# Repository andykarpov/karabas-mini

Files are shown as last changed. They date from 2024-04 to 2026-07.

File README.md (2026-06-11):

# Karabas-Go Mini

A Spartan-6 based devboard to emulate different retro-computers.



The hardware design and documentation are licensed under [Creative Commons Attribution-NonCommercial-ShareAlike 4.0 International](http://creativecommons.org/licenses/by-nc-sa/4.0/).

FPGA cores, the firmware and other software parts are licensed by their own licenses.

### What's on the board:

- A 25k LE's Spartan-6 FPGA
- RP2040 MCU
- 4x USB Ports
- 2x 2MB 10ns SRAM chips
- 32MB SDRAM chip
- DVI output
- On-board FT812 video processor
- SAM2695 midi synth
- 2x microSD cards
- Tape In/Out interface
- DS3221 RTC
- 1kB EEPROM
- ESP8266 Wi-Fi module
- uBUS expansion connector
- ESP32-S3 as VDAC32 mcu
- CF card

### PCB 

The latest stable PCB revision number is Rev.G.

Warning: RevC,D,F requires a small [HW mod](https://github.com/andykarpov/karabas-mini/blob/master/revF_mod.md)

PCB source project: https://github.com/andykarpov/karabas-mini-pcb

### Pre-production renders:

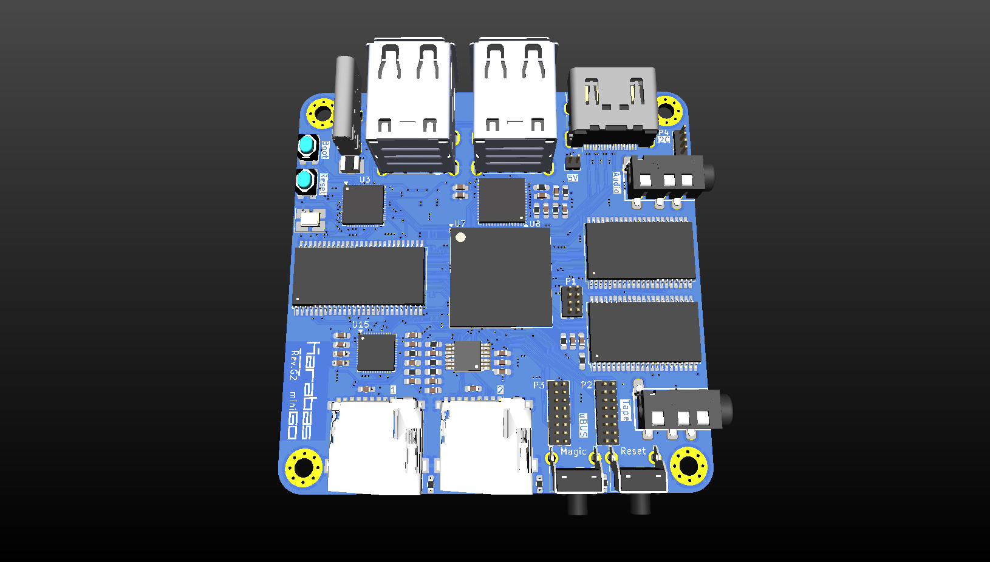
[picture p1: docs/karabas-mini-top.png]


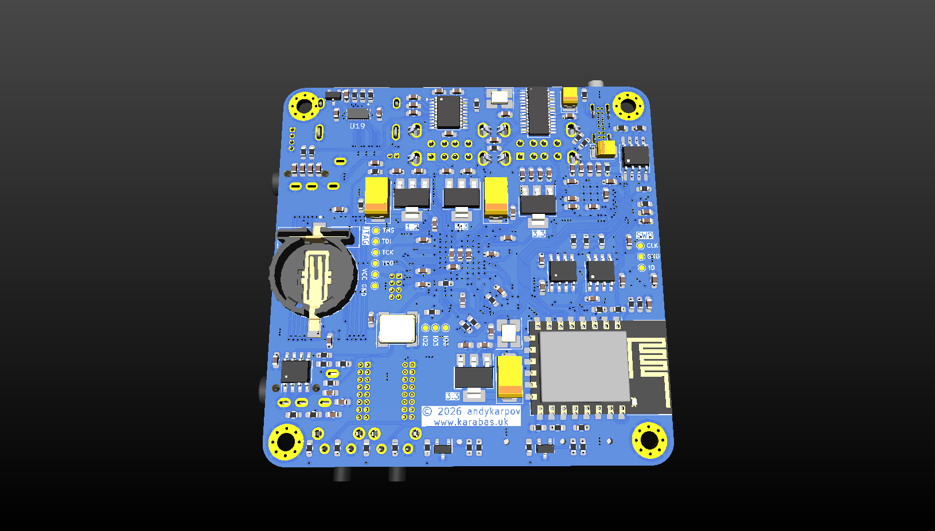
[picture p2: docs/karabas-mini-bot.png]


### Shield with CF card and ESP32-S3 for rev.G (2nd floor)

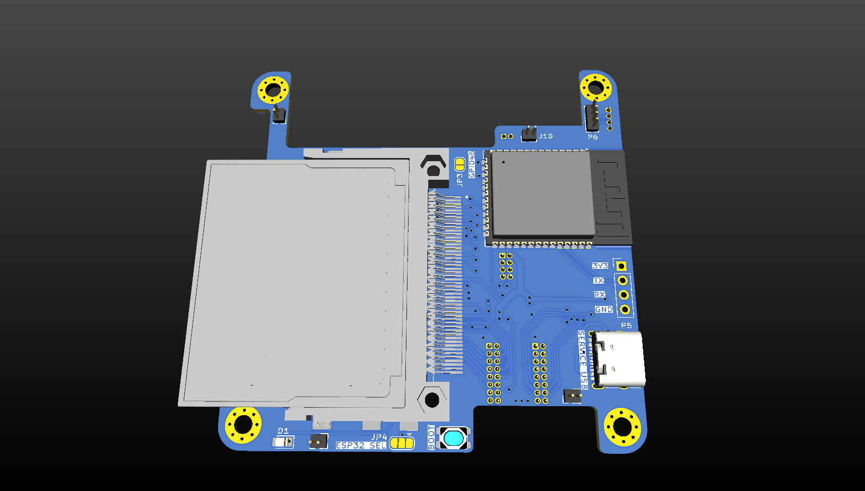
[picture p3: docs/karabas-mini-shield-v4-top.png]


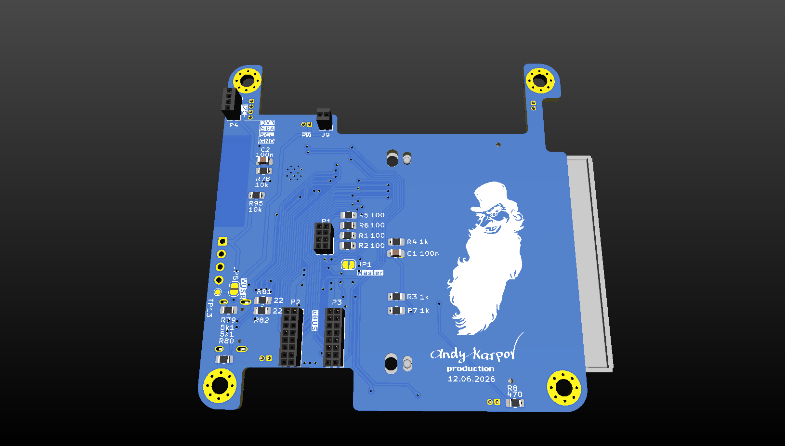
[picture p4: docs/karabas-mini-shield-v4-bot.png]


### Shield for v4 shield with Dot matrix display (3rd floor)

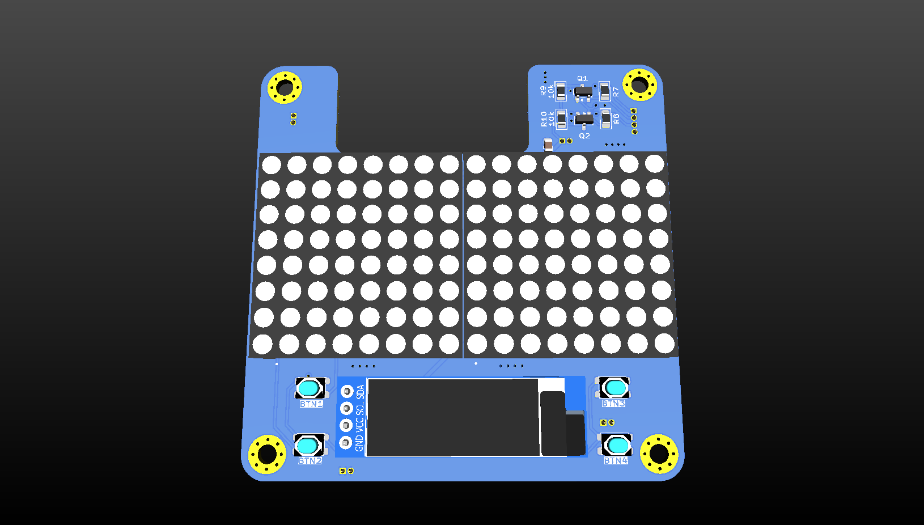
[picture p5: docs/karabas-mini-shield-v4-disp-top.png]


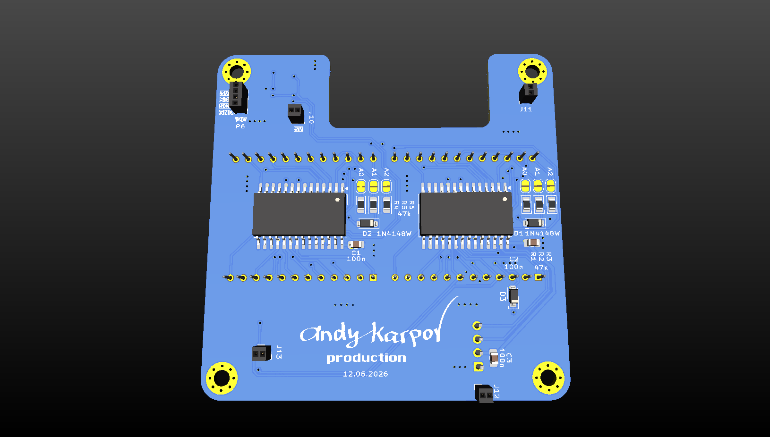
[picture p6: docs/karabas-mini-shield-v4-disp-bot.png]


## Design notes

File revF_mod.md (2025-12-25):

### Required HW mod for all revisions before Rev.G:

The latest cores that uses FT812 chip (boot and tsconf) now requires a generated clock by FPGA instead of 8MHz crystal oscillator.
To perform the mod please do the following:

1. Remove the crystal Y3 (8 MHz)
2. Remove capacitors C40, C41 (18 pF)
3. Find a FPGA net MCU_IO4 and connect it to the Y3 pin 1 by a thin wire





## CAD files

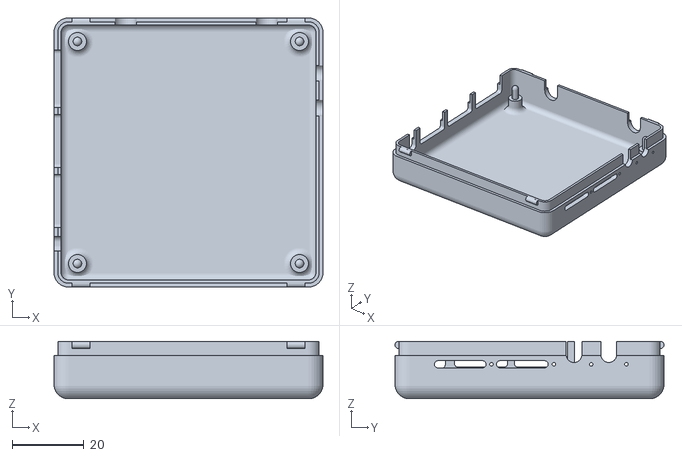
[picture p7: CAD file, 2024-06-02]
case/v2/karabas-mini-case-v2-bottom.stl
75.0 x 75.0 x 16.0

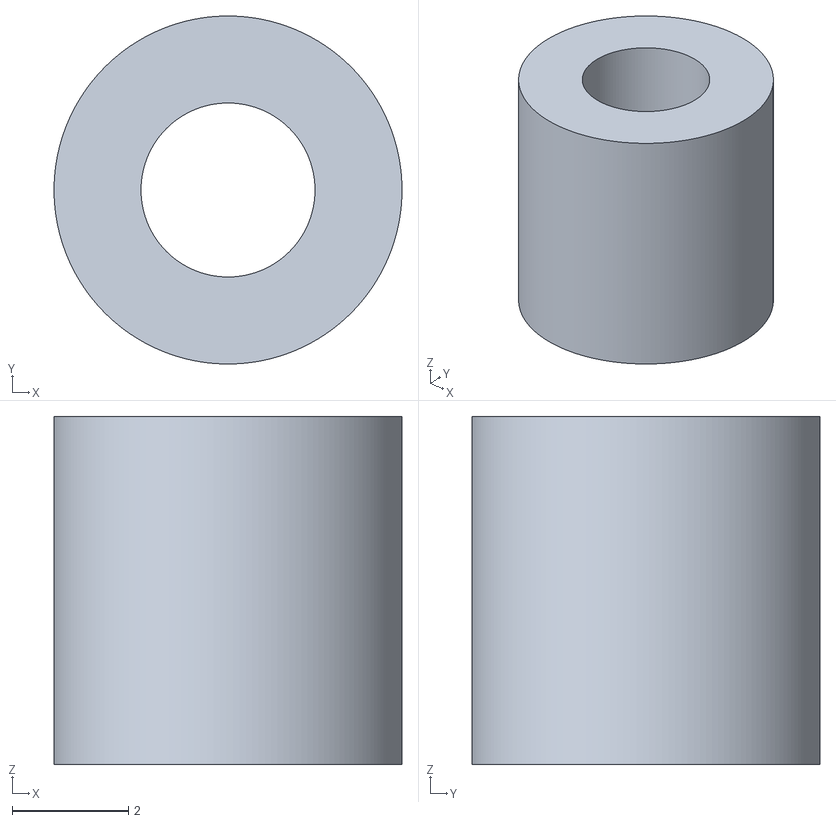
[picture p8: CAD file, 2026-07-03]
case/v2cf/cylinder_6x6x3.stl
6.00 x 6.00 x 6.00

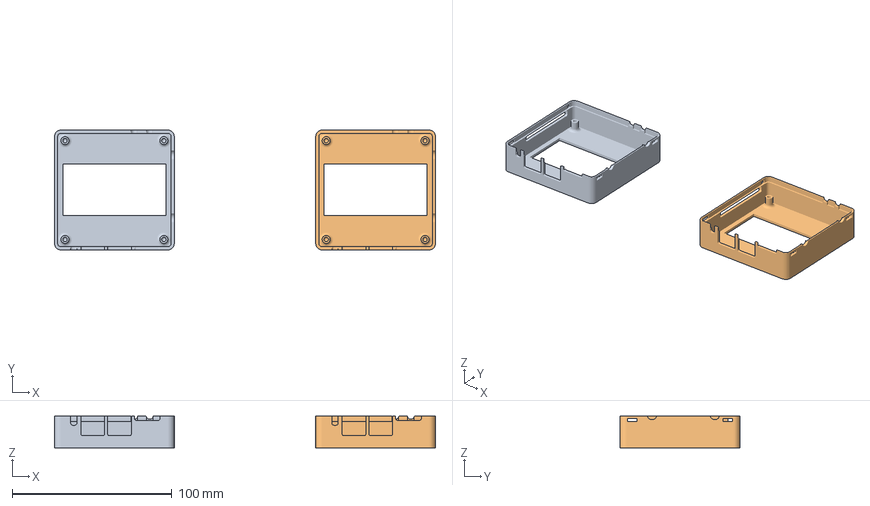
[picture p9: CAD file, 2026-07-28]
case/v4cfdisp/karabas-mini-case-v4cfdisp-top-MMU-LOGO.3mf
238.5 x 75.0 x 20.0 mm

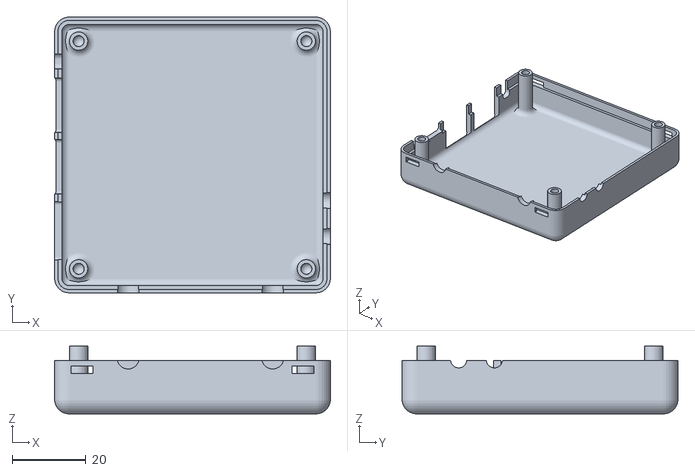
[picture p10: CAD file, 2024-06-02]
case/v2/karabas-mini-case-v2-top.stl
75.0 x 75.0 x 18.4

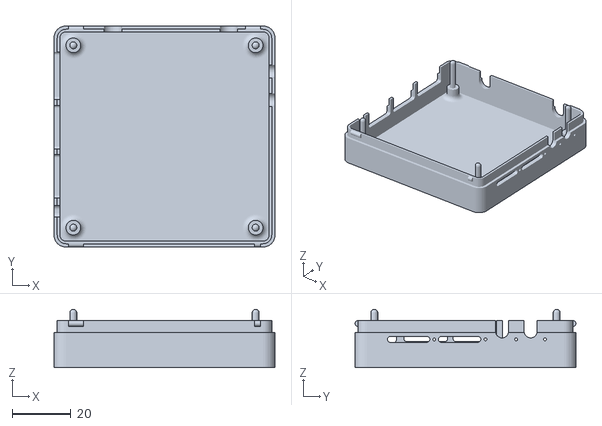
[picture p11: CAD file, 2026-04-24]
case/v2cf/karabas-mini-case-v2cf-bottom.stl
75.0 x 75.0 x 19.8

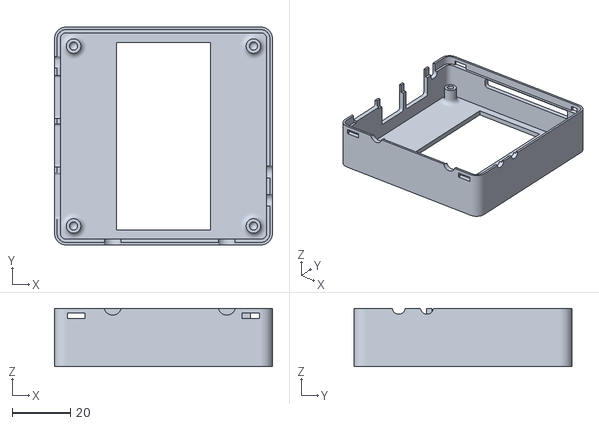
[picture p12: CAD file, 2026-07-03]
case/v4cfdisp/karabas-mini-case-v4cfdisp-top.stl
75.0 x 75.0 x 20.0

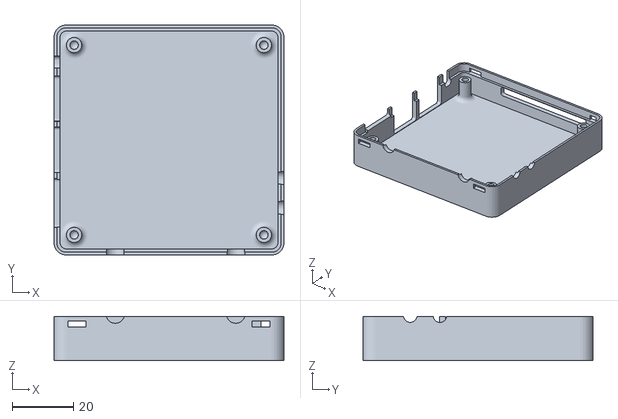
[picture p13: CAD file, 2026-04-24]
case/v2cf/karabas-mini-case-v2cf-top.stl
75.0 x 75.0 x 14.5

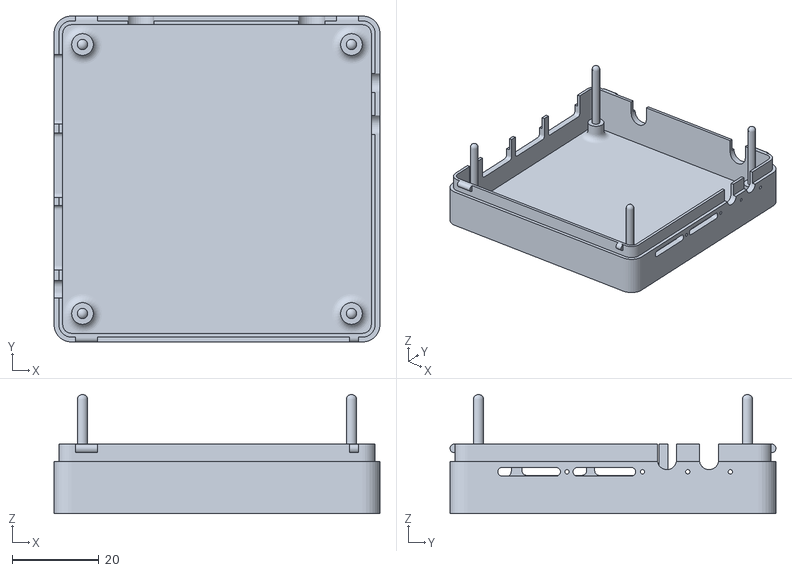
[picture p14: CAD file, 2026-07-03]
case/v4cfdisp/karabas-mini-case-v4cfdisp-bottom.stl
75.0 x 75.0 x 27.4

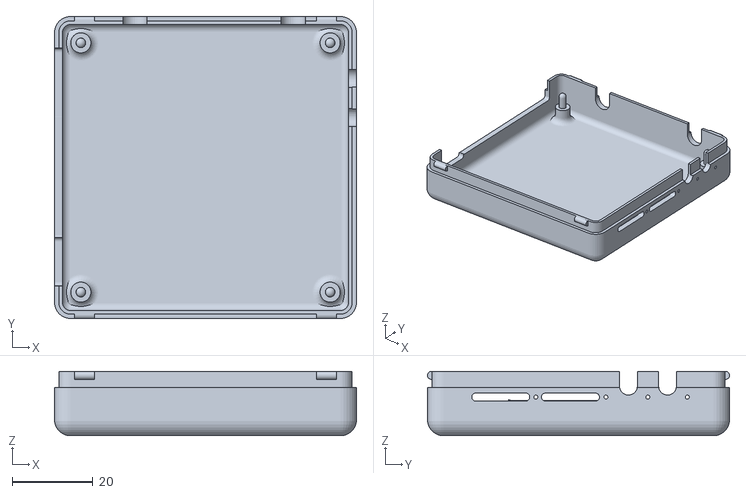
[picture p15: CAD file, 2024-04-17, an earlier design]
case/v1/karabas-mini-case-bottom.stl
75.0 x 75.0 x 16.0

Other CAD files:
case/v1/karabas-mini-case-top.stl

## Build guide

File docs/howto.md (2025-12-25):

# Karabas Go Mini How-to

How to prepare the newly created devboard to run:

1. Prepare an SD card #1 with cores (*.kg2 for rev.C-F3 or *.kg3 for rev.G) and joystick drivers (drivers directory with ini files) in the root of SD card. The SD card should be FAT32 formatted.

2. Upload the RP2040 firmware:

- Press and hold the "RP Boot" button
- Press then release the "RP Reset" button
- Release the "RP Boot" button
- Put the firmware.uf2 (for rev.C - rev.F3) or firmware_g.uf2 renamed to firmware.uf2 (for rev.G) into a mounted drive
- Wait a bit until it reboots
- Done, the boot.kg2 on rev.C-rev.F3 or boot.kg3 on rev.G core should starts
- Please read the manual of each core what to place on SD2 for each of them

3. Upload the ESP32-S3 firmware:

- Close jumper JP11
- Power the main board with USB-C
- Connect a secondary USB-C cable to the upper board
- edit (change the com port address) and run the flash.bat (or flash.sh)
- after successful flashing, remove the JP11 jumper, disconnect both USB-C cables

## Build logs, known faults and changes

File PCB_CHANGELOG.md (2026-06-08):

## Rev.G2

- replaced UDA1334A with PCM5102A
- aligned SDRAM tracks

## Rev.G

- removed crystal from FT812
- removed MCU_IO4 connection from RP2040
- the MCU_IO4 line now repurposed as FT812 8MHz clk generated by FPGA
- disconnected FT_AUDIO, FT_DISPLAY from FPGA
- PWM audio replaced with UDA1334 DAC
- disconnected FT_PD from FPGA, connected to RP2040 as FT_RESET
- disconnected MIDI_CLK from FPGA, replaced with 12 MHz crystal
- disconnected MIDI_RST from FPGA, connected to RP2040
- disconnected ESP_BOOT and ESP_RESET from FPGA
- connected ESP_RESET to RP2040
- connected FT812 GPIO0 and GPIO1 and FT SPI to the uBUS header
- connected free FPGA pins to the uBUS as I2S slave pins
- added optional diode to the HDMI 5V line
- rerouted MCU_SCK, ADC_BCK and FT_CLK to the FPGA globak clock pins

Warning: Due to so many backward incompatible changes in the Rev.G, a dedicated firmware (\_g.uf2) and cores (.kg3) will be released for this revision.
Do not try to install the default firmware and cores (kg2) on this revision!

## Rev.F (F1, F2, F3)

- replaced USB Type-C connector with a flag-style one

## Rev.E

- Skipped

## Rev.D

- Small improvements to the rev.C

## Rev.C

- Initial Revision

## Rev.A, Rev.B

- Unreleased due to broken FPGA pinout

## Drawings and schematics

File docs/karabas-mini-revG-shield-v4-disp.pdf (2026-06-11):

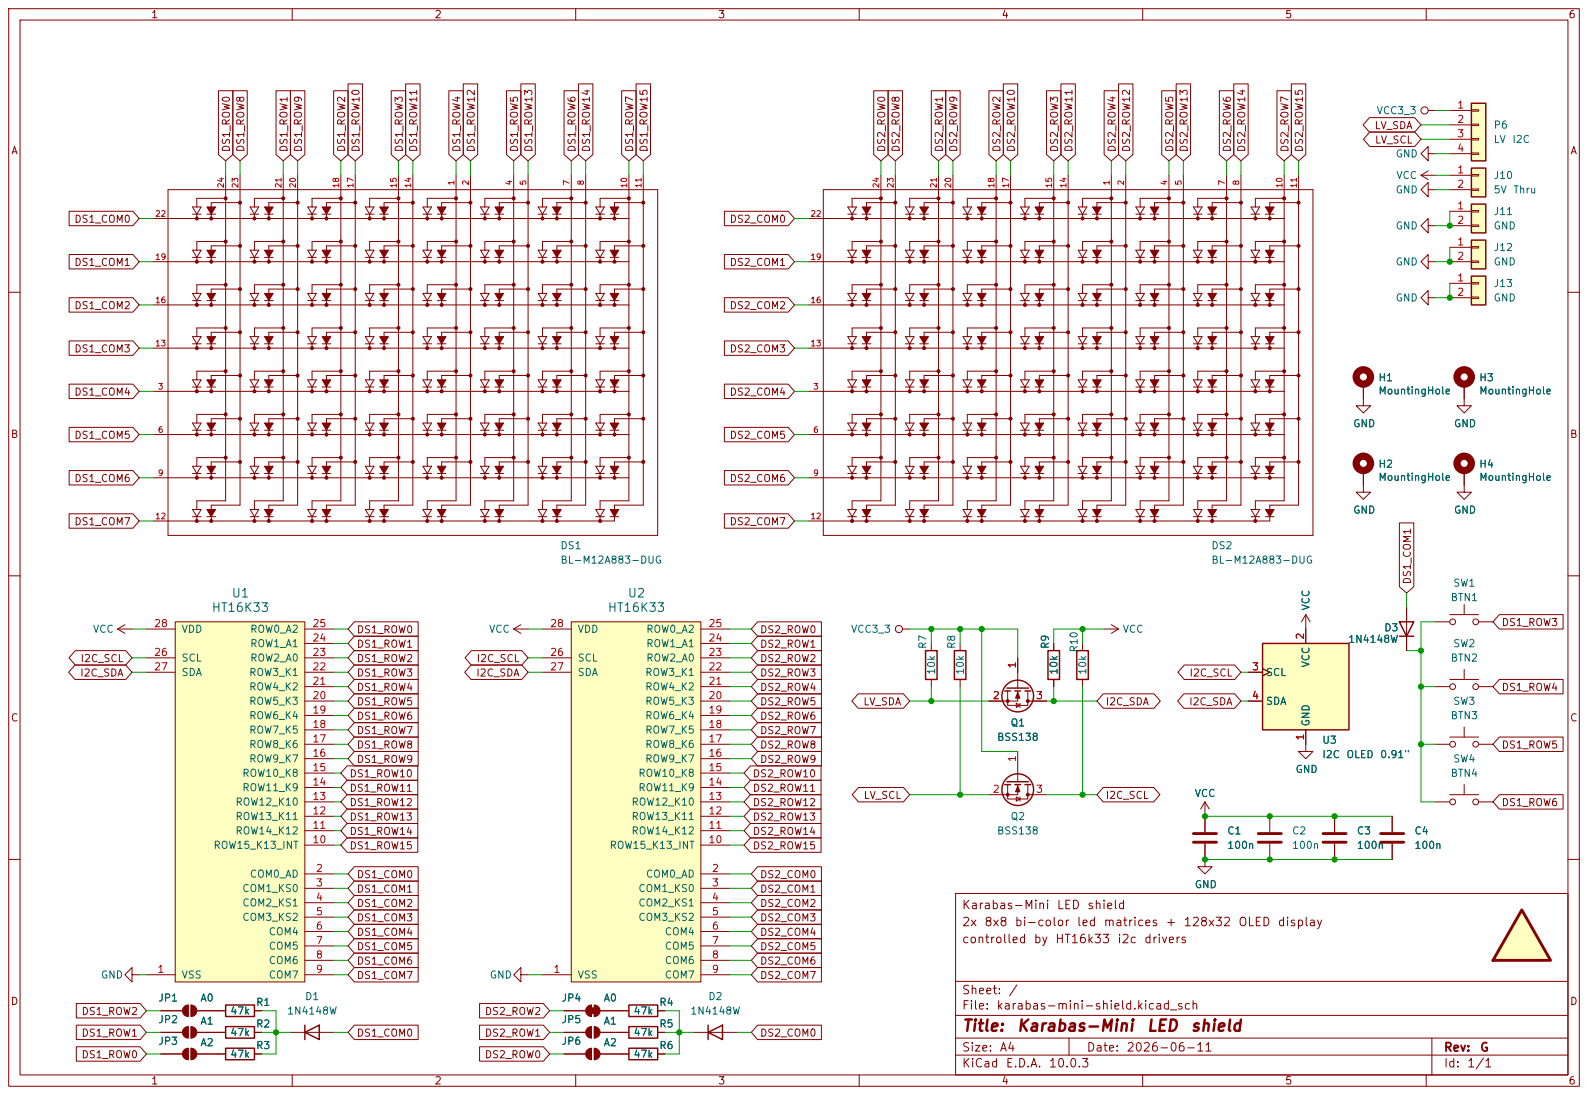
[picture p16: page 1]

Karabas-Mini LED shield
2x 8x8 bi-color led matrices + 128x32 OLED display
controlled by HT16k33 i2c drivers

Sheet: /
File: karabas-mini-shield.kicad_sch
Title: Karabas-Mini LED shield

Size: A4 | Rev: G
KiCad E.D.A. 10.0.3 | Id: 1/1

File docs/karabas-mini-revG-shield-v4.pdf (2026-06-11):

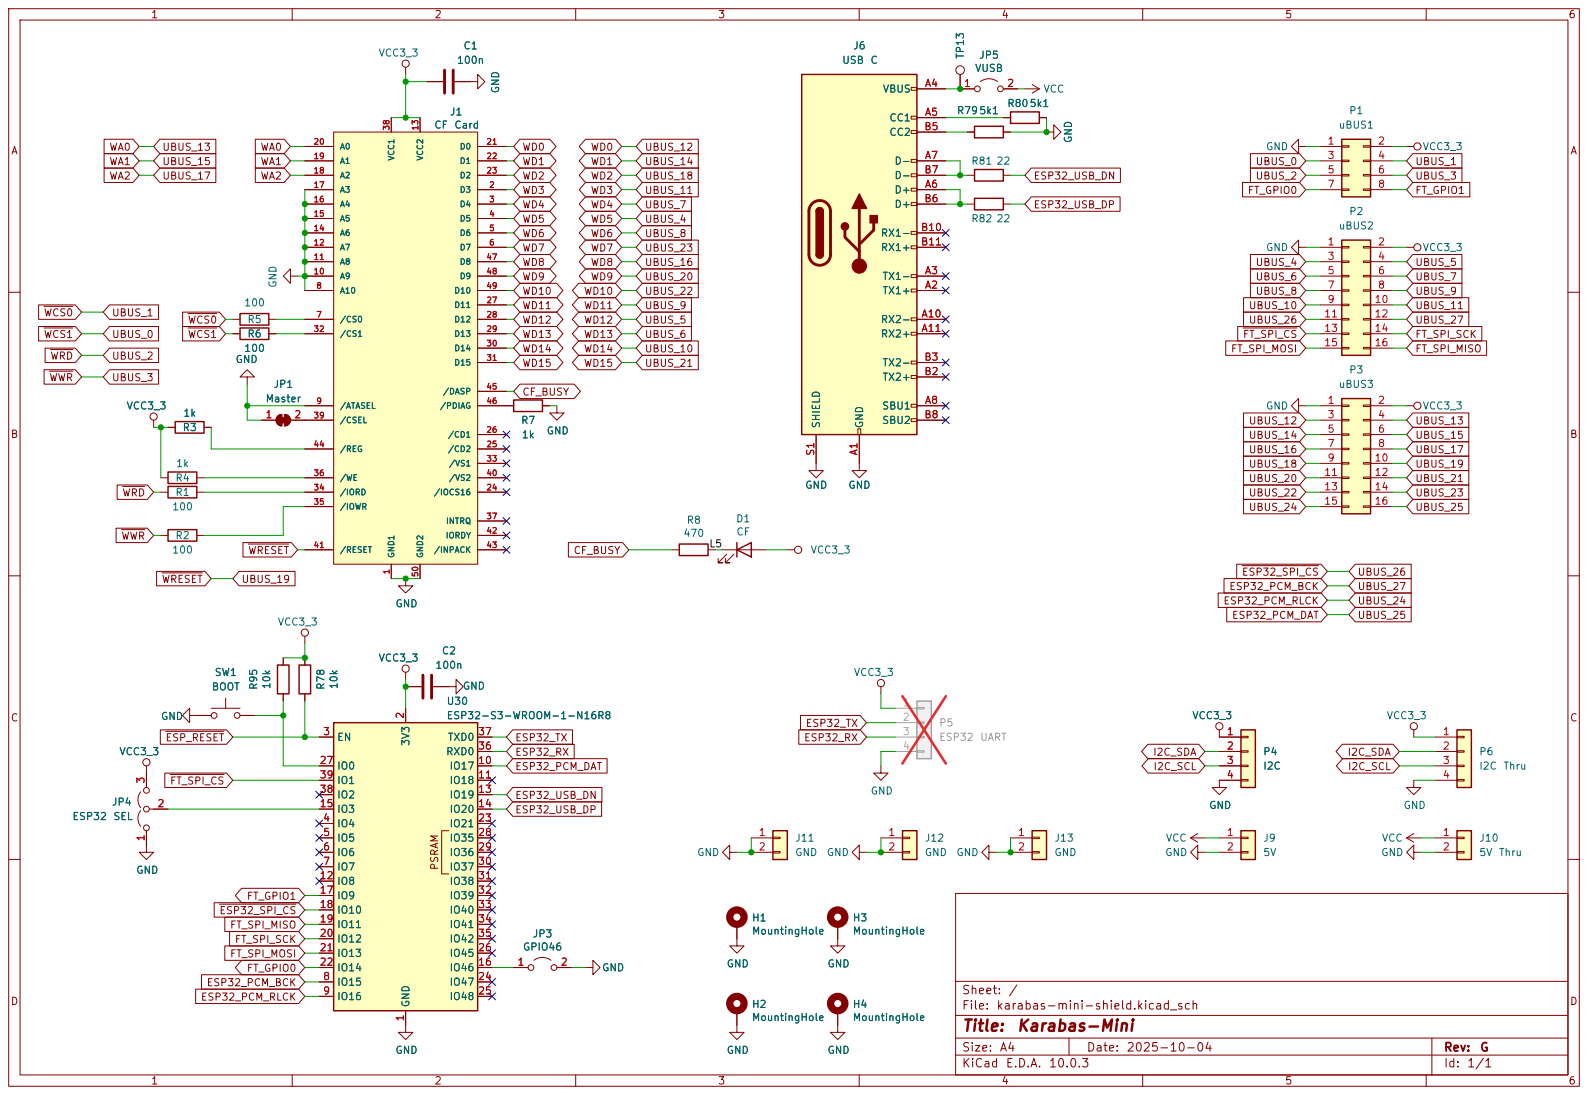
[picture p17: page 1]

Sheet: /
File: karabas-mini-shield.kicad_sch
Title: Karabas-Mini

Size: A4 | Rev: G
KiCad E.D.A. 10.0.3 | Id: 1/1

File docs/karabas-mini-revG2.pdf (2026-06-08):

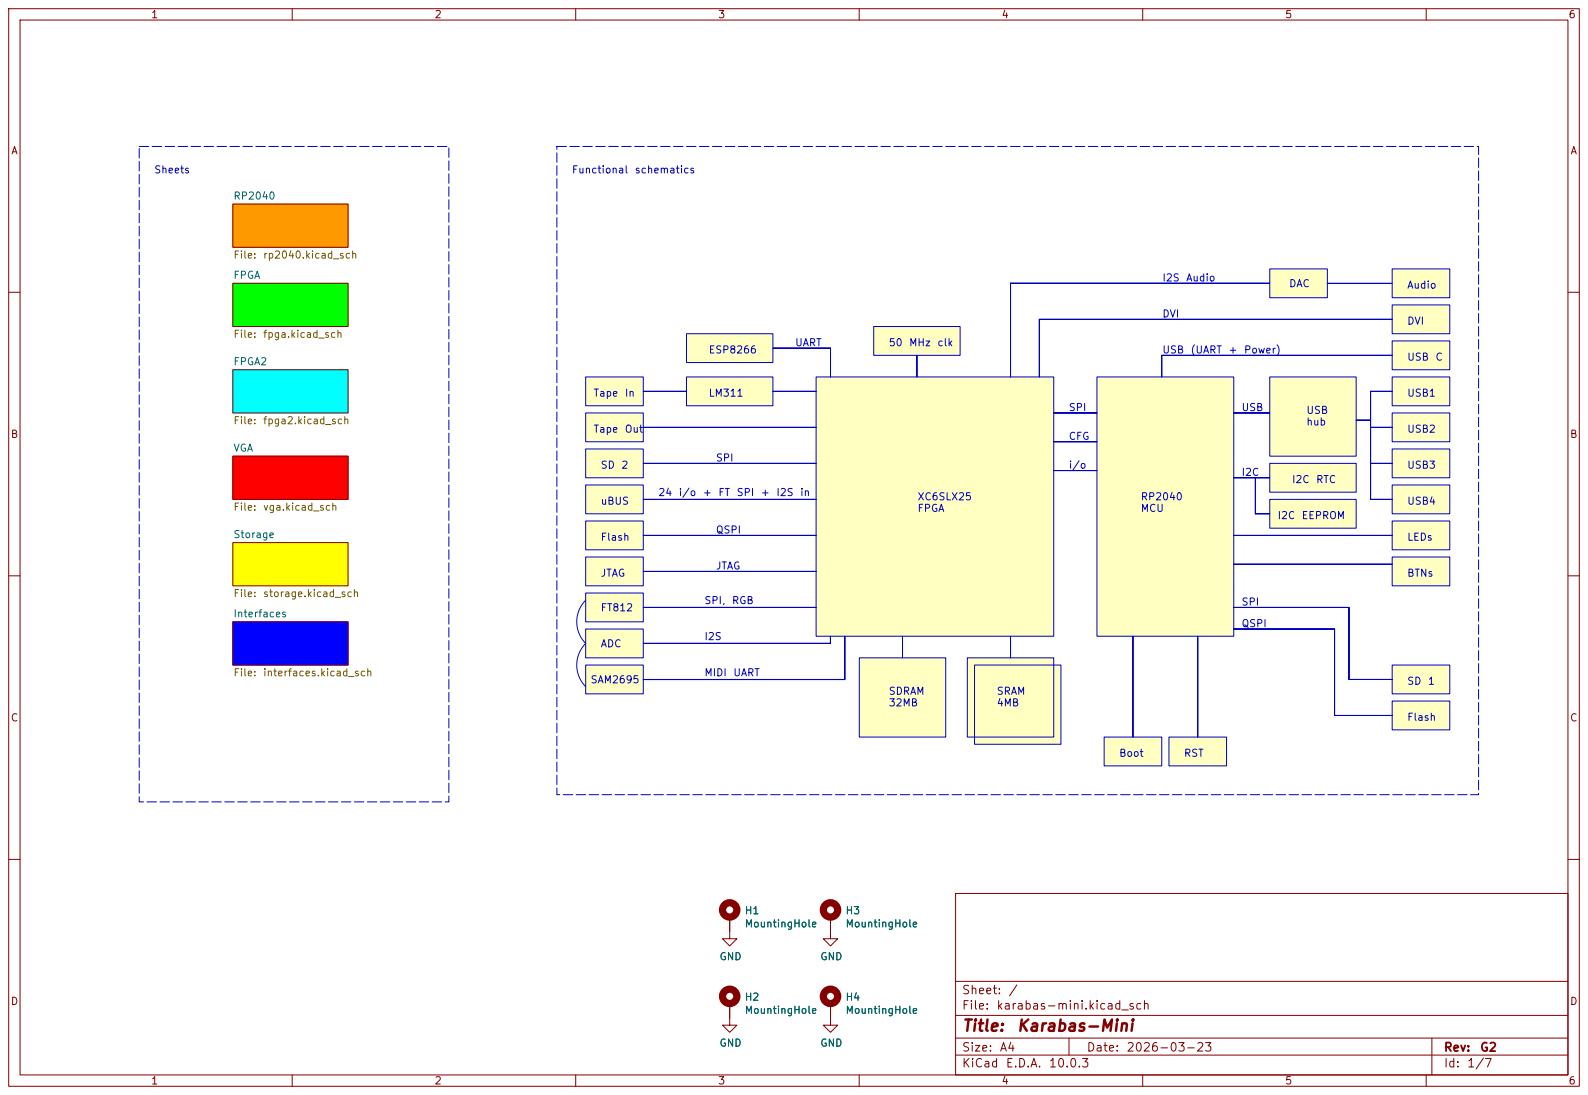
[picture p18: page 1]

Functional schematics 24 i/o + FT SPI + I2S in

Size: A4 | Rev: G2
KiCad E.D.A. 10.0.3 | Id: 1/7

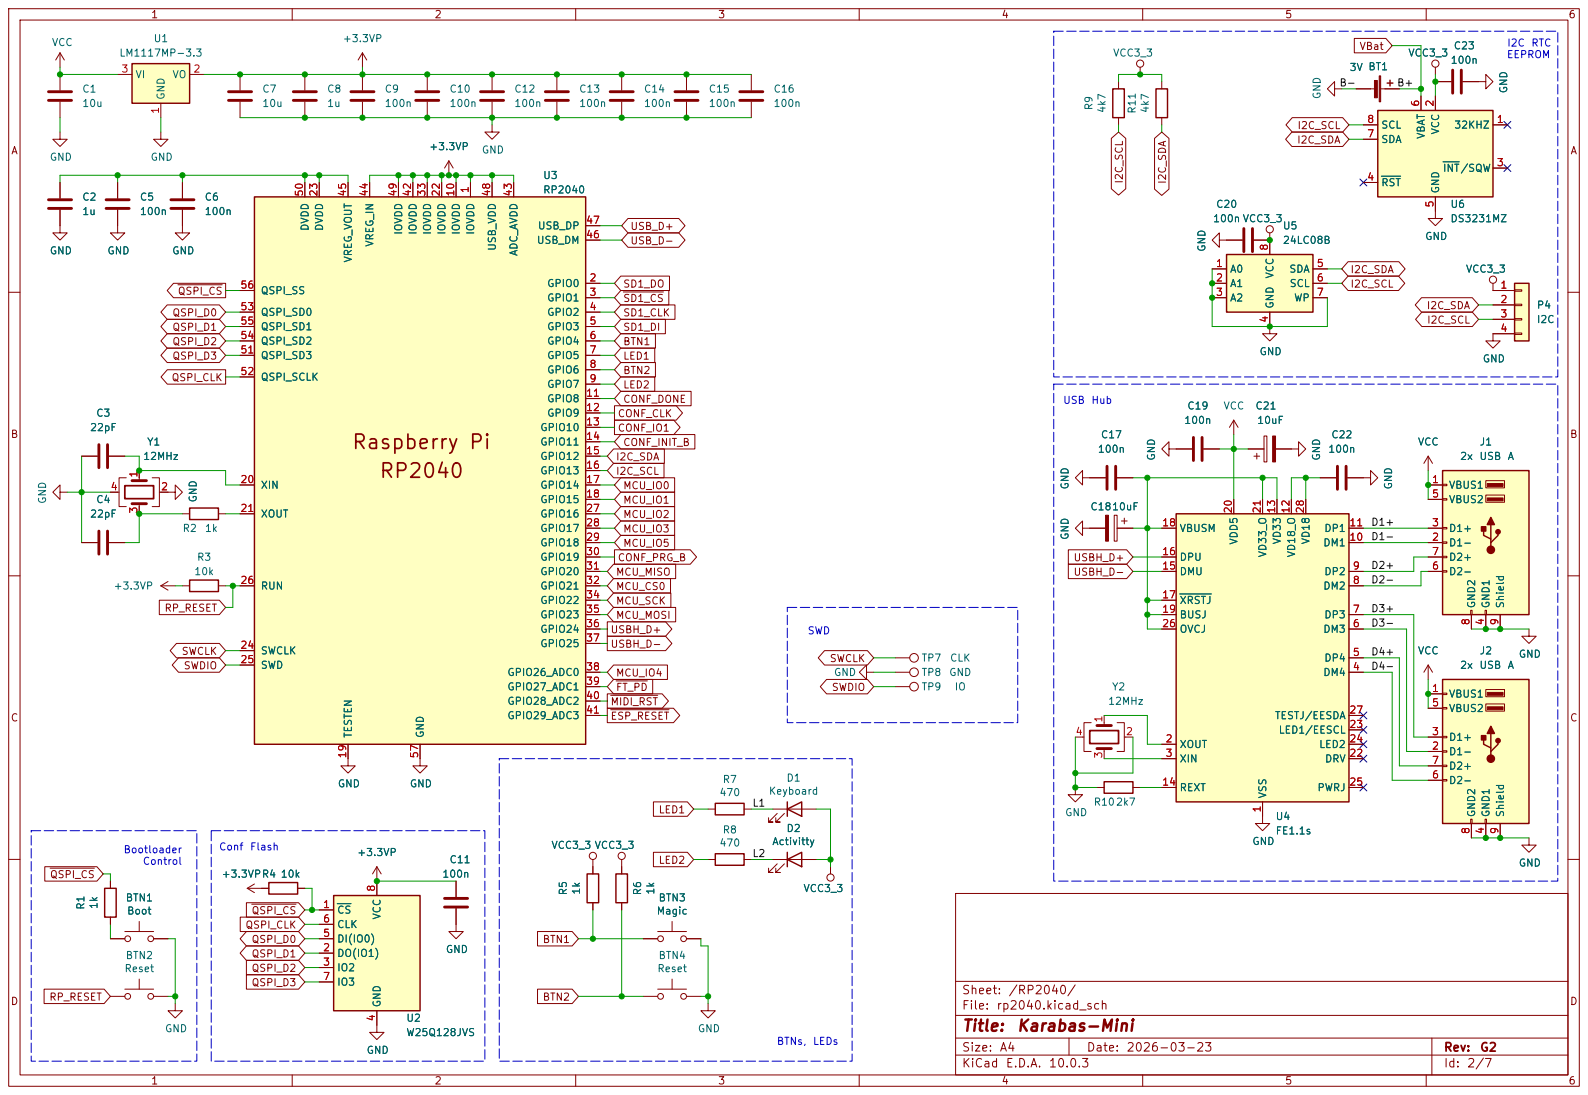
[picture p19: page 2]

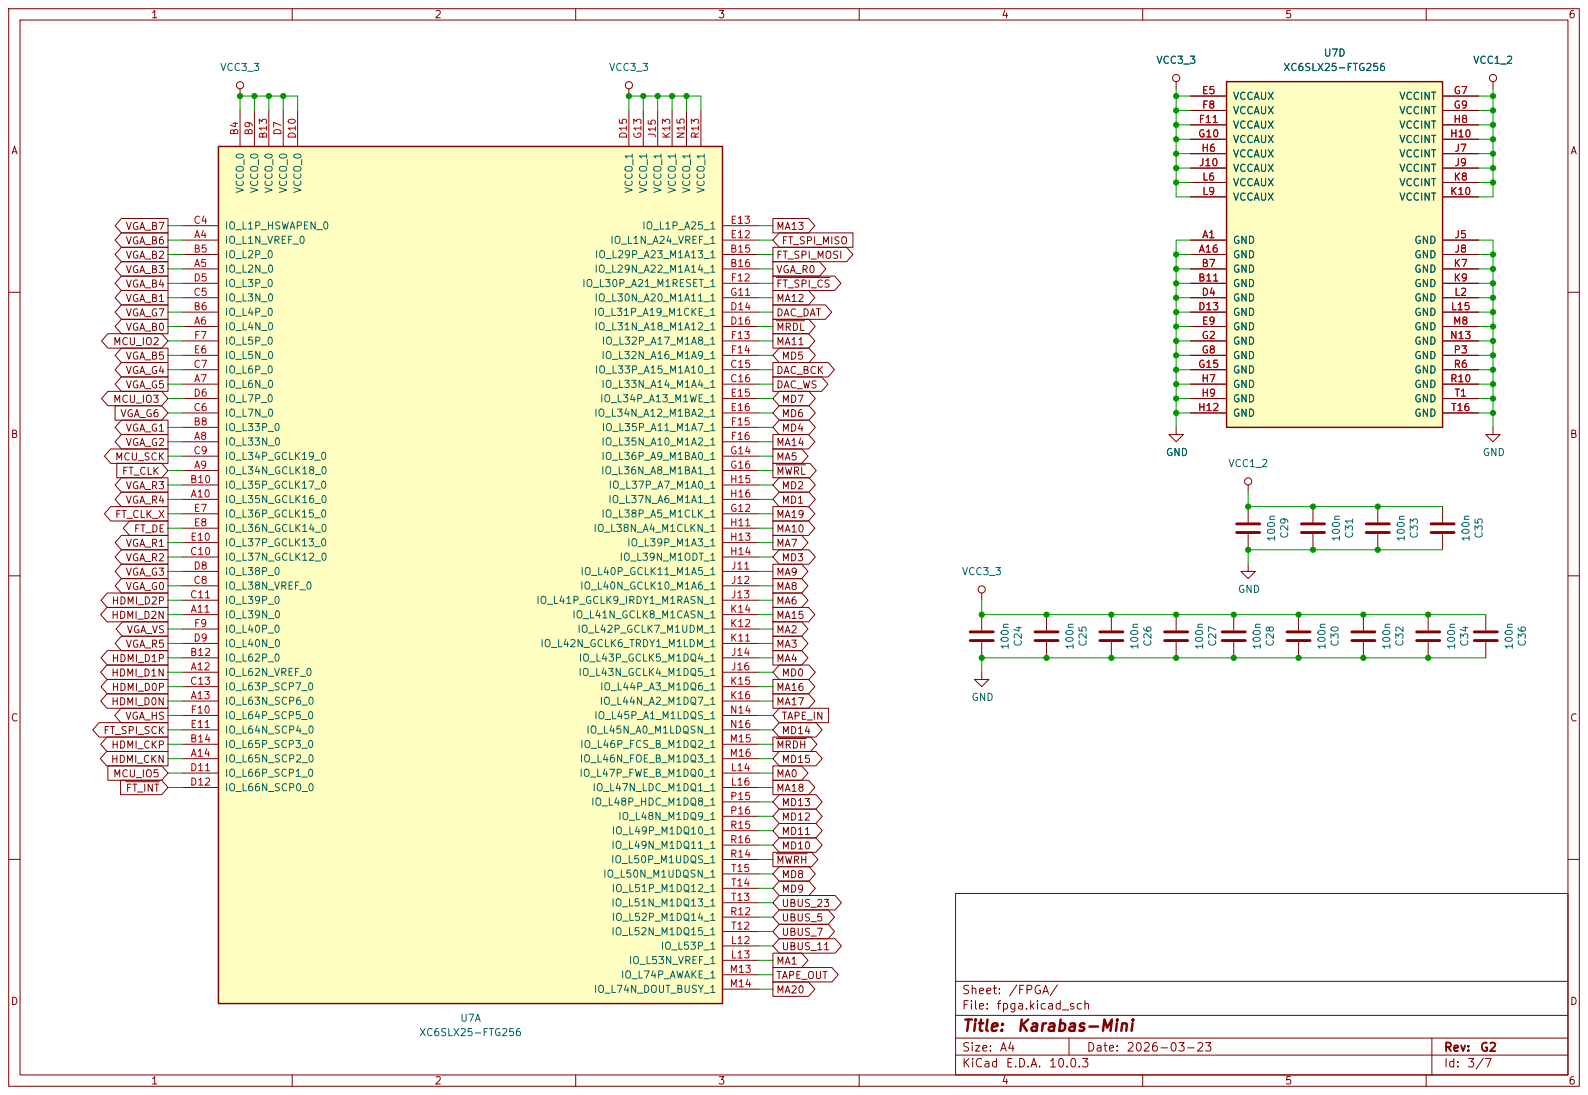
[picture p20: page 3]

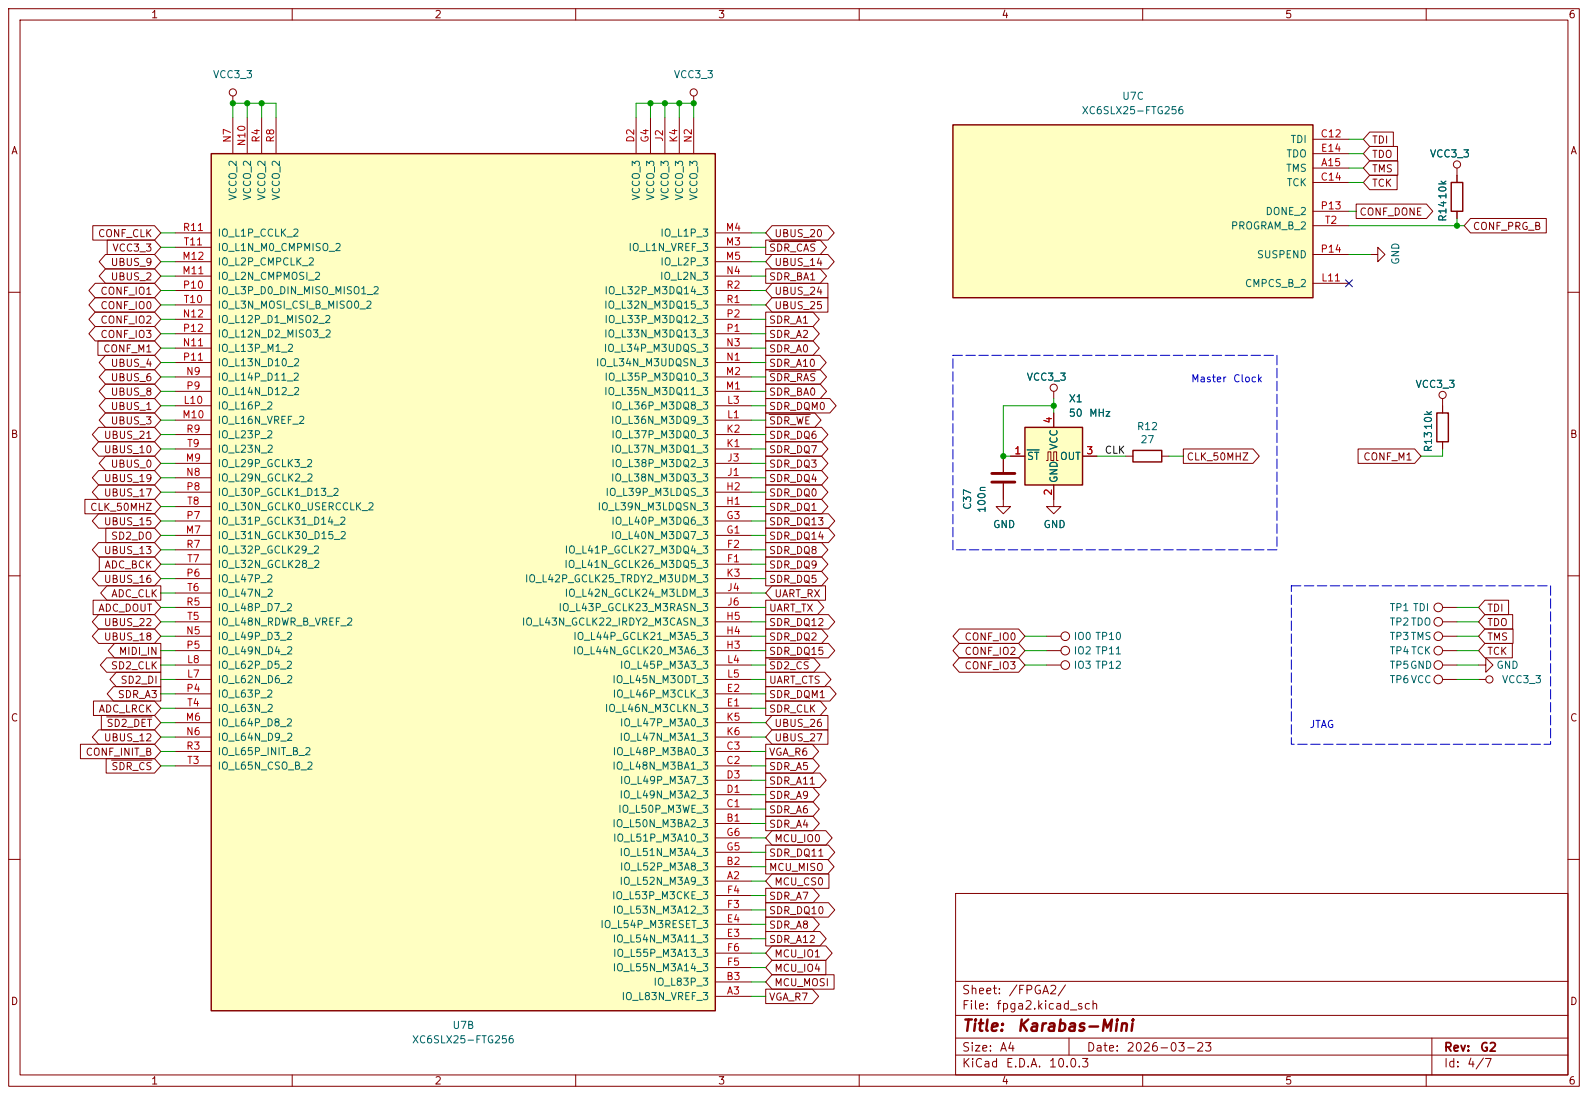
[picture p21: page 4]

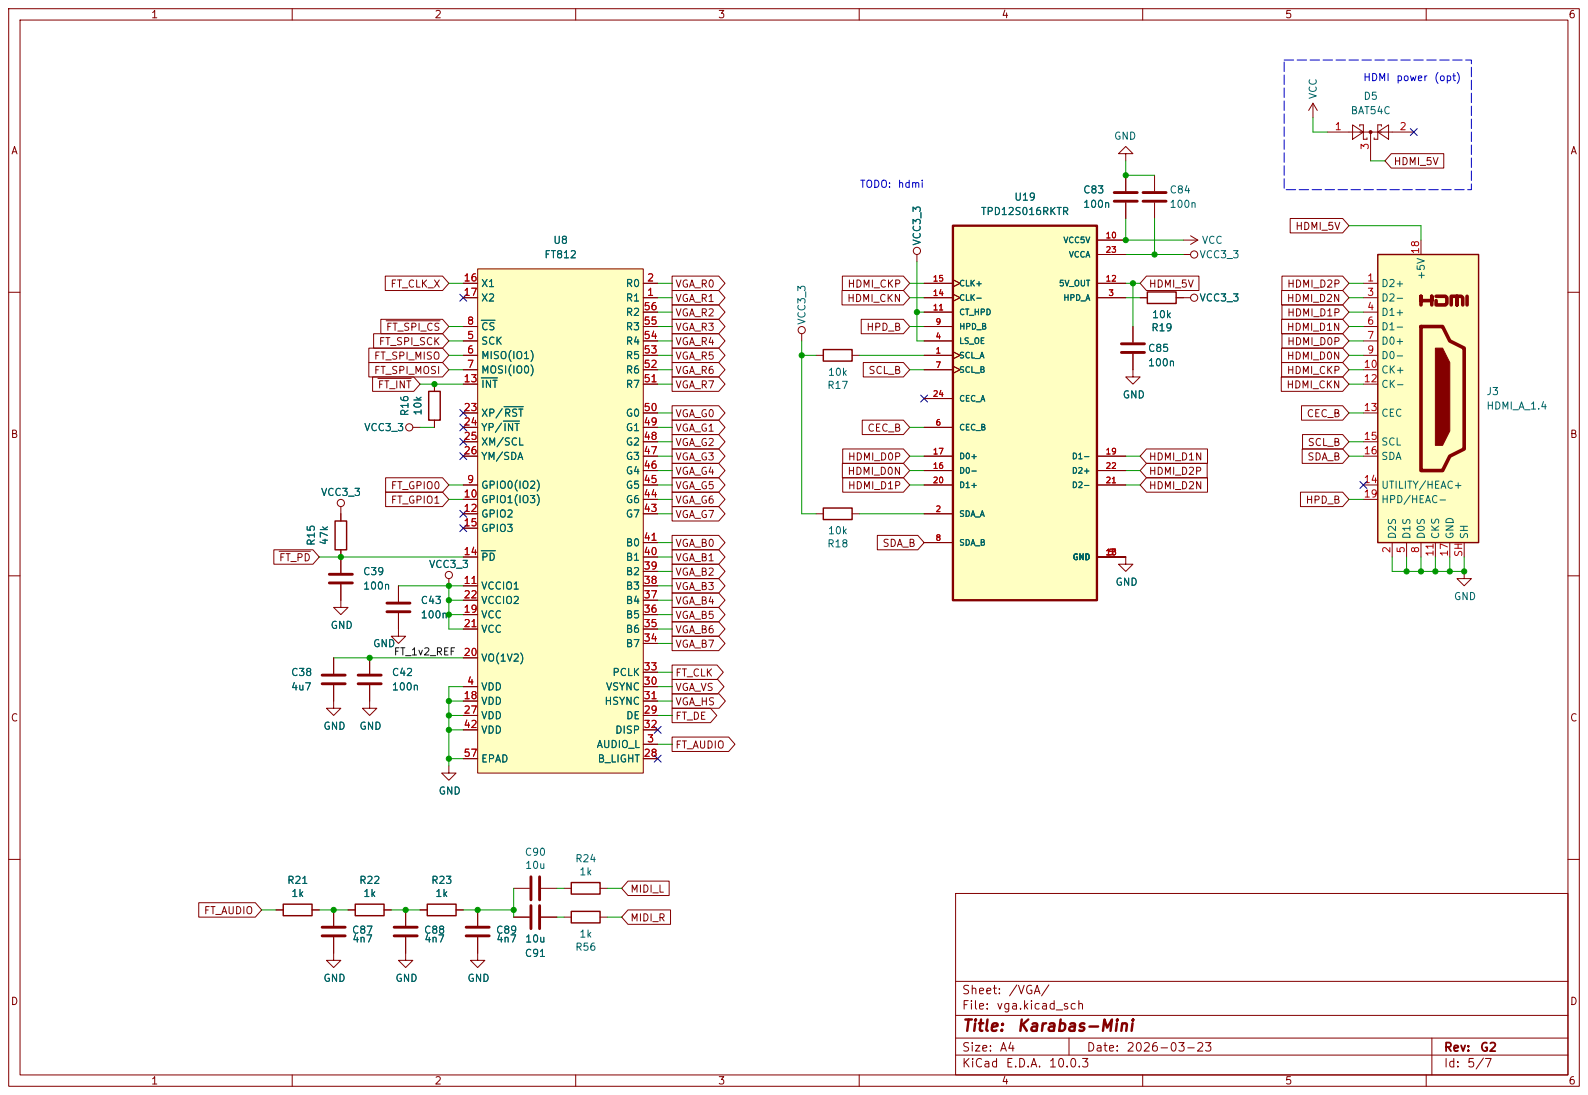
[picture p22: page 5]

XP/RST 23
YP/INT 24
XM/SCL 25
YM/SDA 26
VSYNC 30 HSYNC 31 DISP 32 PCLK 33 B7 34 B6 35 B5 36 B4 37 B3 38 B2 39 B1 40 B0 41

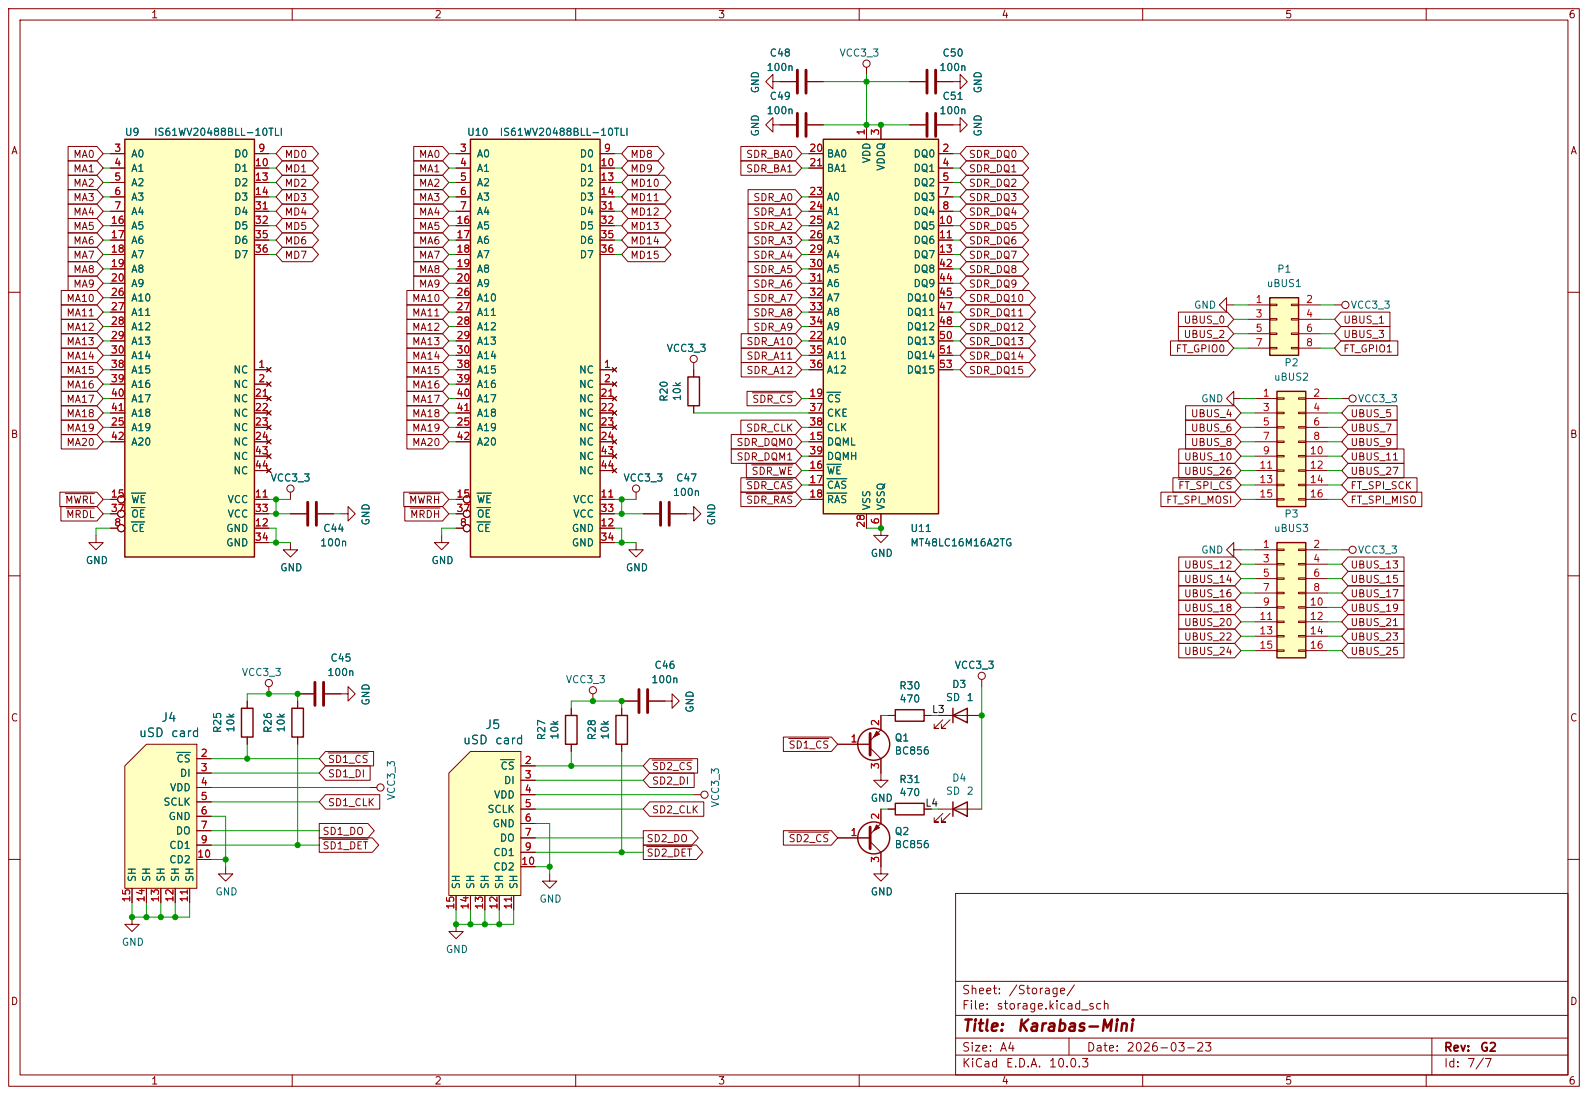
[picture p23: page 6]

6 DQ3 7 DQ4 8 DQ5 10 DQ6 11 DQ7 13 DQML 15 WE 16 CAS 17 RAS 18 CS 19 BA0 20 BA1 21

SCLK 5 GND 6 DO 7 CD1 9 CD2 10 SH 11 SH 12 SH 13 SH 14 SH 15

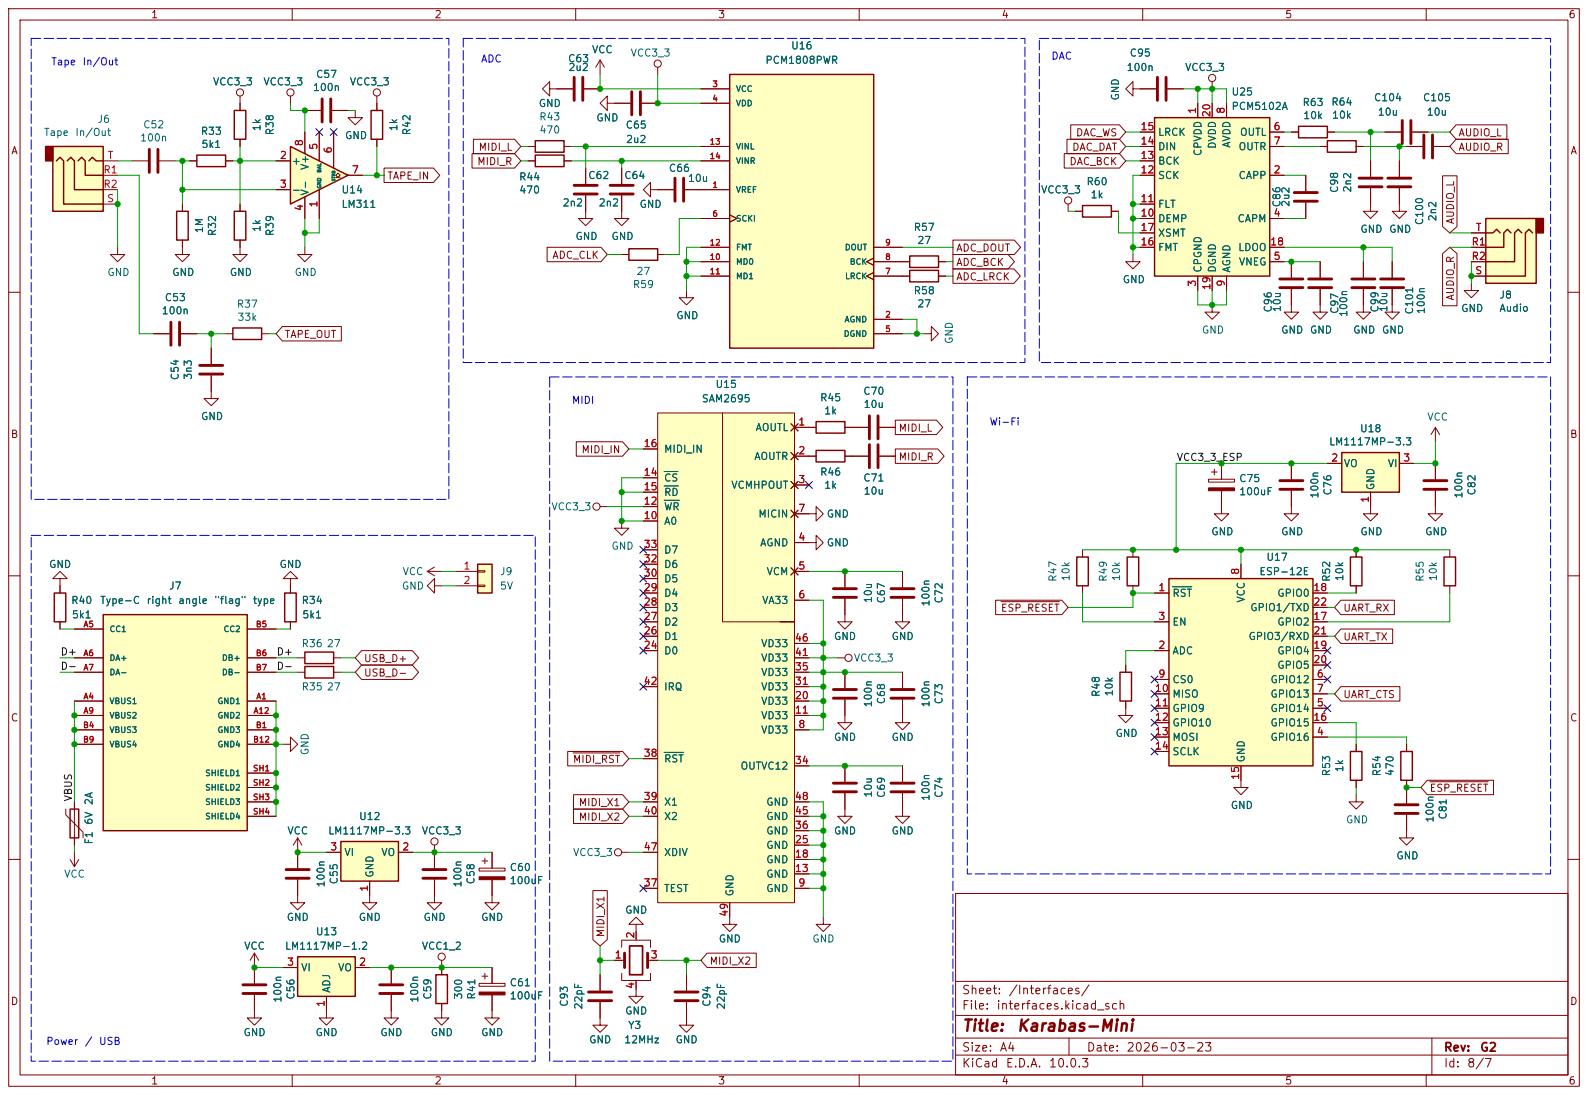
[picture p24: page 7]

10u C98 2n2 GND
SCK 12 BCK 13 DIN 14 LRCK 15

Type-C right angle "flag" type 100n C56 R35 27 R34
Type-C right angle "flag" type

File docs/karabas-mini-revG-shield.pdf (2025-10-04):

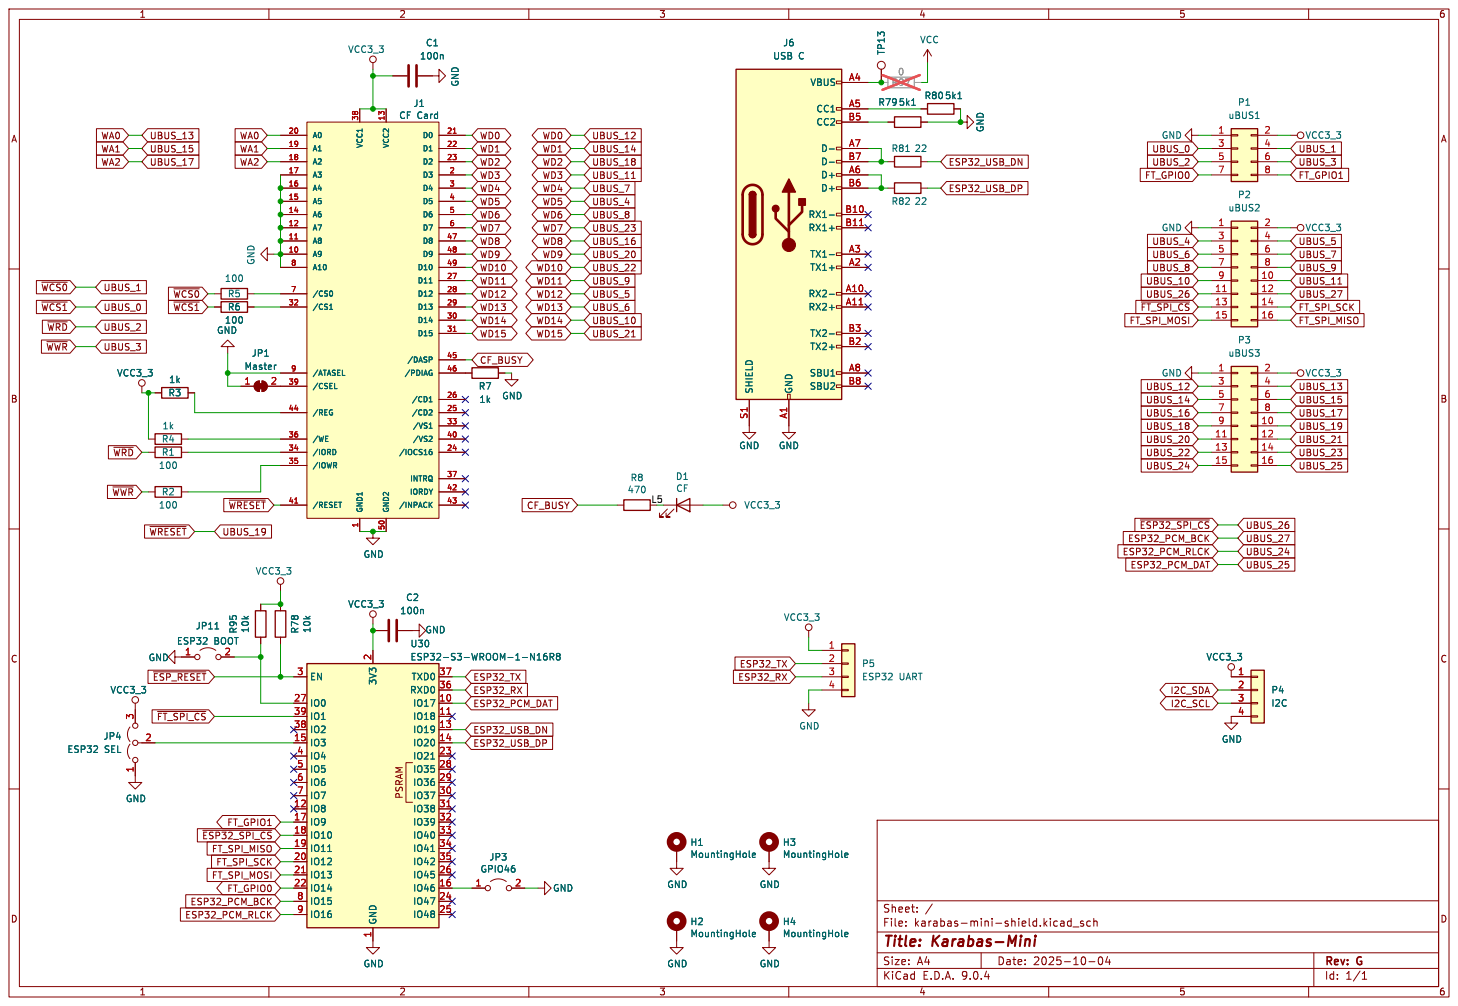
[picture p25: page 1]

Id: 1/1 Title: Karabas-Mini File: karabas-mini-shield.kicad_sch Sheet: / GND

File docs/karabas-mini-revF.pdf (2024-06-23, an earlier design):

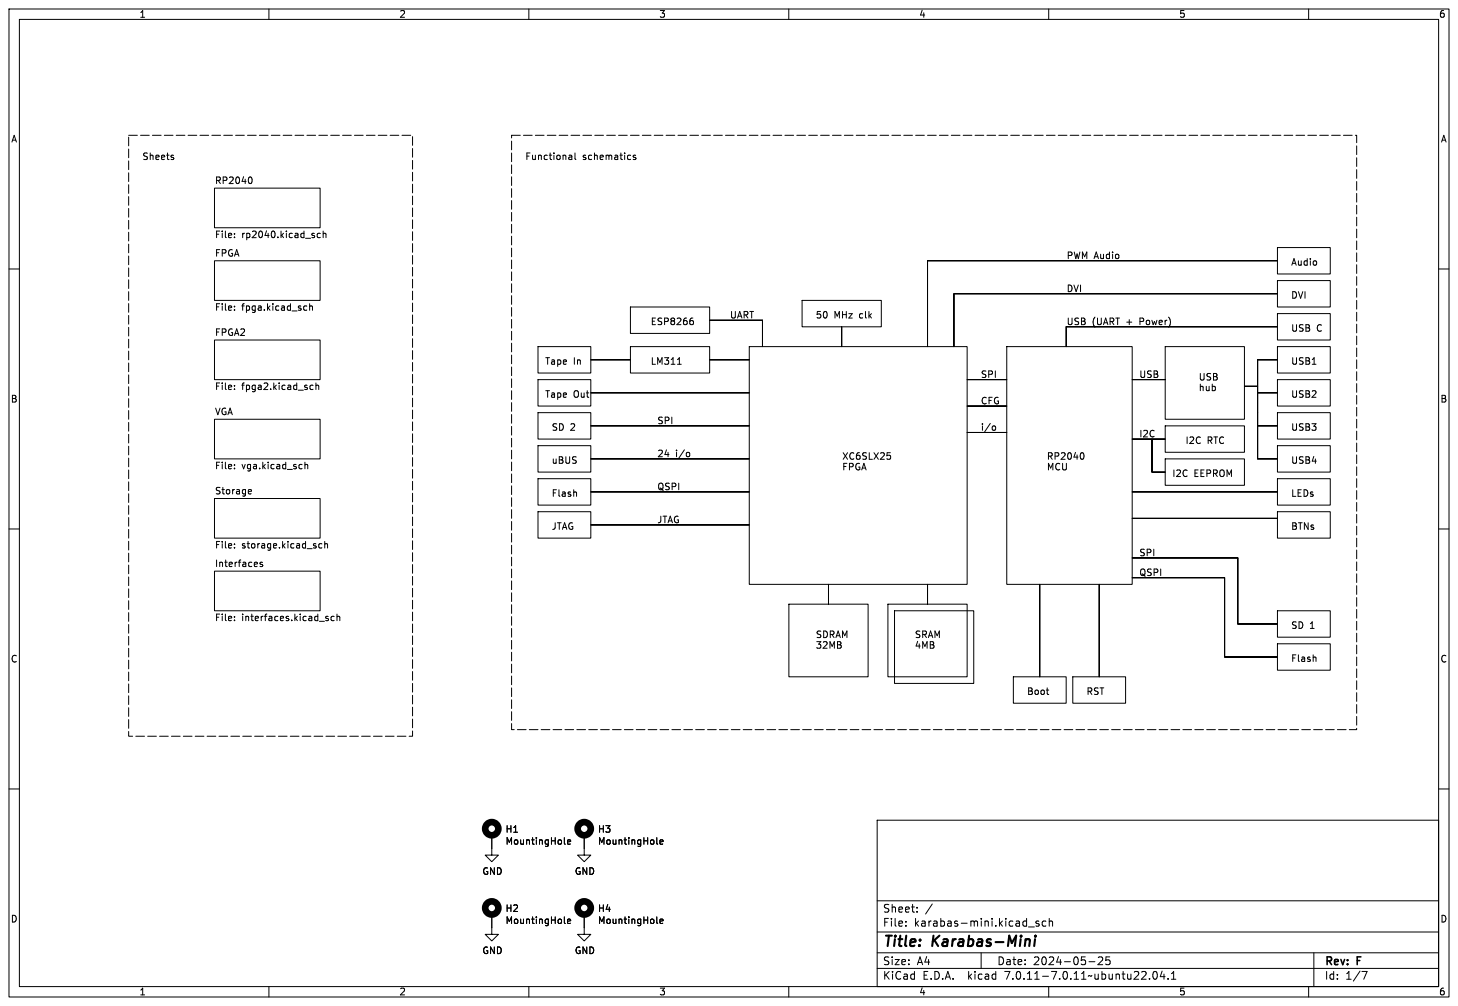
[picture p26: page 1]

File: fpga.kicad_sch RP2040 File: rp2040.kicad_sch VGA
Interfaces File: interfaces.kicad_sch FPGA

Id: 1/7 Title: Karabas-Mini File: karabas-mini.kicad_sch Sheet: /

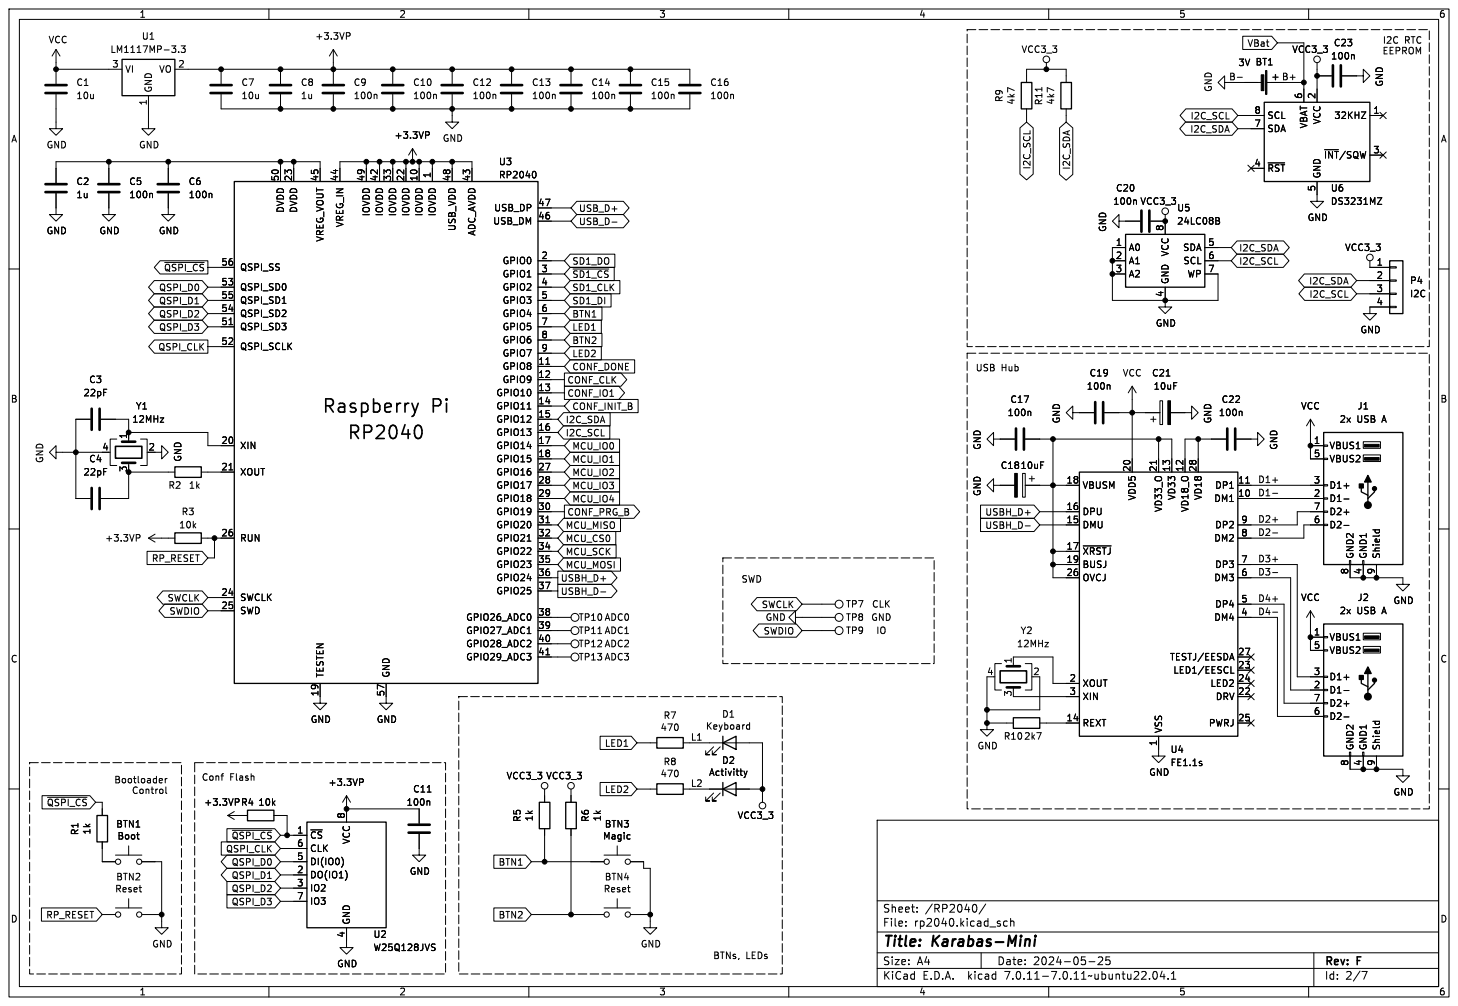
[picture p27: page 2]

6 SDA 7 SCL 8 U6 DS3231MZ GND R9 4k7 VCC3_3 GND GND R11 4k7 VCC C21

6 SDA 7 SCL 8 GND GND

1 IOVDD 10 GPIO8 11 GPIO9 12 GPIO10 13 GPIO11 14 GPIO12 15 GPIO13 16 GPIO14 17 GPIO15 18 TESTEN 19 GPIO0 2 XIN 20 XOUT 21 IOVDD 22 DVDD 23 SWCLK 24 SWD 25 RUN 26 GPIO16 27 GPIO17 28 GPIO18 29 GPIO1 3 GPIO19 30 GPIO20 31 GPIO21 32 IOVDD 33 GPIO22 34 GPIO23 35 GPIO24 36 GPIO25 37 GPIO26_ADC0 38 GPIO27_ADC1 39 GPIO2 4 GPIO28_ADC2 40 GPIO29_ADC3 41 IOVDD 42 ADC_AVDD 43 VREG_IN 44 VREG_VOUT 45 USB_DM 46 USB_DP 47 USB_VDD 48 IOVDD 49 GPIO3 5 DVDD 50 QSPI_SD3 51 QSPI_SCLK 52 QSPI_SD0 53 QSPI_SD2 54 QSPI_SD1 55 QSPI_SS 56 GND 57 GPIO4 6 GPIO5 7 GPIO6 8 GPIO7 9 U3 RP2040 TP11 ADC1 C2

1 IOVDD 10 GPIO8 11 GPIO9 12 GPIO10 13 GPIO11 14 GPIO12 15 GPIO13 16 GPIO14 17 GPIO15 18 TESTEN 19 GPIO0 2 XIN 20 XOUT 21 IOVDD 22 DVDD 23 SWCLK 24 SWD 25 RUN 26 GPIO16 27 GPIO17 28 GPIO18 29 GPIO1 3 GPIO19 30 GPIO20 31 GPIO21 32 IOVDD 33 GPIO22 34 GPIO23 35 GPIO24 36 GPIO25 37 GPIO26_ADC0 38 GPIO27_ADC1 39 GPIO2 4 GPIO28_ADC2 40 GPIO29_ADC3 41 IOVDD 42 ADC_AVDD 43 VREG_IN 44 VREG_VOUT 45 USB_DM 46 USB_DP 47 USB_VDD 48 IOVDD 49 GPIO3 5 DVDD 50 QSPI_SD3 51 QSPI_SCLK 52 QSPI_SD0 53 QSPI_SD2 54 QSPI_SD1 55 QSPI_SS 56 GND 57 GPIO4 6 GPIO5 7 GPIO6 8 GPIO7 9 Y1
TP10 ADC0 C5

4 SDA 5 SCL 6 WP 7 VCC

1 DM1 10 DP1 11 VD18_O 12 VD33 13 REXT 14 DMU 15 DPU 16 ~{XRSTJ} 17 VBUSM 18 BUSJ 19 XOUT 2 VDD5 20 VD33_O 21 DRV 22

Id: 2/7 Title: Karabas-Mini File: rp2040.kicad_sch Sheet: /RP2040/



Id: 4/7 Title: Karabas-Mini File: fpga2.kicad_sch Sheet: /FPGA2/


Id: 5/7 Title: Karabas-Mini File: vga.kicad_sch Sheet: /VGA/ C87


1 DQ5 10 DQ6 11 DQ7 13 DQML 15 ~{WE} 16 ~{CAS} 17 ~{RAS} 18 ~{CS} 19 DQ0 2 BA0 20 BA1 21 A10 22 A0 23 A1 24 A2 25 A3 26 VSS 28 A4 29 VDDQ

3 A5 30 A6 31 A7 32 A8 33 A9 34 A11 35 A12 36 CKE 37 CLK 38 DQMH 39 DQ1 4 DQ8 42 DQ9 44 DQ10 45 DQ11 47 DQ12 48 DQ2 5 DQ13 50 DQ14 51 DQ15 53 VSSQ

uBUS3 CD2 10 SH 11 SH 12 SH 13 SH 14 SH 15

~{CS}2 DI 3 VDD 4 SCLK 5 GND 6 DO 7 CD1 9 J4

~{CS}2 DI 3 VDD 4 SCLK 5 GND 6 DO 7 CD1 9 J5


1 VO 2 VI 3 GND GND GND GND R53 1k C75

8 CS0 9 U17 ESP-12E GND C81 100n R54 470 GND GND

1 VO 2 VI 3 VCC GND C59 100n GND

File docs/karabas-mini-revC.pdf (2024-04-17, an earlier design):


File: fpga.kicad_sch RP2040 File: rp2040.kicad_sch VGA
Interfaces File: interfaces.kicad_sch FPGA

Id: 1/7 Title: Karabas-Mini File: karabas-mini.kicad_sch Sheet: /


6 SDA 7 SCL 8 U6 DS3231MZ GND GND GND GND

6 SDA 7 SCL 8 GND GND

1 IOVDD 10 GPIO8 11 GPIO9 12 GPIO10 13 GPIO11 14 GPIO12 15 GPIO13 16 GPIO14 17 GPIO15 18 TESTEN 19 GPIO0 2 XIN 20 XOUT 21 IOVDD 22 DVDD 23 SWCLK 24 SWD 25 RUN 26 GPIO16 27 GPIO17 28 GPIO18 29 GPIO1 3 GPIO19 30 GPIO20 31 GPIO21 32 IOVDD 33 GPIO22 34 GPIO23 35 GPIO24 36 GPIO25 37 GPIO26_ADC0 38 GPIO27_ADC1 39 GPIO2 4 GPIO28_ADC2 40 GPIO29_ADC3 41 IOVDD 42 ADC_AVDD 43 VREG_IN 44 VREG_VOUT 45 USB_DM 46 USB_DP 47 USB_VDD 48 IOVDD 49 GPIO3 5 DVDD 50 QSPI_SD3 51 QSPI_SCLK 52 QSPI_SD0 53 QSPI_SD2 54 QSPI_SD1 55 QSPI_SS 56 GND 57 GPIO4 6 GPIO5 7 GPIO6 8 GPIO7 9 U3 RP2040 TP10 ADC0 GND
VCC3_3 GND

1 IOVDD 10 GPIO8 11 GPIO9 12 GPIO10 13 GPIO11 14 GPIO12 15 GPIO13 16 GPIO14 17 GPIO15 18 TESTEN 19 GPIO0 2 XIN 20 XOUT 21 IOVDD 22 DVDD 23 SWCLK 24 SWD 25 RUN 26 GPIO16 27 GPIO17 28 GPIO18 29 GPIO1 3 GPIO19 30 GPIO20 31 GPIO21 32 IOVDD 33 GPIO22 34 GPIO23 35 GPIO24 36 GPIO25 37 GPIO26_ADC0 38 GPIO27_ADC1 39 GPIO2 4 GPIO28_ADC2 40 GPIO29_ADC3 41 IOVDD 42 ADC_AVDD 43 VREG_IN 44 VREG_VOUT 45 USB_DM 46 USB_DP 47 USB_VDD 48 IOVDD 49 GPIO3 5 DVDD 50 QSPI_SD3 51 QSPI_SCLK 52 QSPI_SD0 53 QSPI_SD2 54 QSPI_SD1 55 QSPI_SS 56 GND 57 GPIO4 6 GPIO5 7 GPIO6 8 GPIO7 9 GND

4 SDA 5 SCL 6 WP 7 VCC

1 DM1 10 DP1 11 VD18_O 12 VD33 13 REXT 14 DMU 15 DPU 16 ~{XRSTJ} 17 VBUSM 18 BUSJ 19 XOUT 2 VDD5 20 VD33_O 21 DRV 22

Id: 2/7 Title: Karabas-Mini File: rp2040.kicad_sch Sheet: /RP2040/




Id: 5/7 Title: Karabas-Mini File: vga.kicad_sch Sheet: /VGA/


1 DQ5 10 DQ6 11 DQ7 13 DQML 15 ~{WE} 16 ~{CAS} 17 ~{RAS} 18 ~{CS} 19 DQ0 2 BA0 20 BA1 21 A10 22 A0 23 A1 24 A2 25 A3 26 VSS 28 A4 29 VDDQ

3 A5 30 A6 31 A7 32 A8 33 A9 34 A11 35 A12 36 CKE 37 CLK 38 DQMH 39 DQ1 4 DQ8 42 DQ9 44 DQ10 45 DQ11 47 DQ12 48 DQ2 5 DQ13 50 DQ14 51 DQ15 53 VSSQ

VCC3_3 R25 10k VCC3_3
~{CS}2 DI 3 VDD 4 SCLK 5 GND 6 DO 7 CD1 9 J4

~{CS}2 DI 3 VDD 4 SCLK 5 GND 6 DO 7 CD1 9 J5

Id: 7/7 Title: Karabas-Mini File: storage.kicad_sch Sheet: /Storage/ CD2 10 SH 11 SH 12 SH 13 SH 14 SH 15


8 CS0 9 U17 ESP-12E GND R55 10k GND C73 100n C81 100n C76 100n GND

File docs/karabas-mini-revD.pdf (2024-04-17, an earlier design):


File: fpga.kicad_sch RP2040 File: rp2040.kicad_sch VGA
Interfaces File: interfaces.kicad_sch FPGA
Flash SD 2 GND GND

Id: 1/7 Title: Karabas-Mini File: karabas-mini.kicad_sch Sheet: /


6 SDA 7 SCL 8 U6 DS3231MZ GND GND GND GND

6 SDA 7 SCL 8 GND GND

1 IOVDD 10 GPIO8 11 GPIO9 12 GPIO10 13 GPIO11 14 GPIO12 15 GPIO13 16 GPIO14 17 GPIO15 18 TESTEN 19 GPIO0 2 XIN 20 XOUT 21 IOVDD 22 DVDD 23 SWCLK 24 SWD 25 RUN 26 GPIO16 27 GPIO17 28 GPIO18 29 GPIO1 3 GPIO19 30 GPIO20 31 GPIO21 32 IOVDD 33 GPIO22 34 GPIO23 35 GPIO24 36 GPIO25 37 GPIO26_ADC0 38 GPIO27_ADC1 39 GPIO2 4 GPIO28_ADC2 40 GPIO29_ADC3 41 IOVDD 42 ADC_AVDD 43 VREG_IN 44 VREG_VOUT 45 USB_DM 46 USB_DP 47 USB_VDD 48 IOVDD 49 GPIO3 5 DVDD 50 QSPI_SD3 51 QSPI_SCLK 52 QSPI_SD0 53 QSPI_SD2 54 QSPI_SD1 55 QSPI_SS 56 GND 57 GPIO4 6 GPIO5 7 GPIO6 8 GPIO7 9 U3 RP2040 TP10 ADC0 GND
VCC3_3 GND

1 IOVDD 10 GPIO8 11 GPIO9 12 GPIO10 13 GPIO11 14 GPIO12 15 GPIO13 16 GPIO14 17 GPIO15 18 TESTEN 19 GPIO0 2 XIN 20 XOUT 21 IOVDD 22 DVDD 23 SWCLK 24 SWD 25 RUN 26 GPIO16 27 GPIO17 28 GPIO18 29 GPIO1 3 GPIO19 30 GPIO20 31 GPIO21 32 IOVDD 33 GPIO22 34 GPIO23 35 GPIO24 36 GPIO25 37 GPIO26_ADC0 38 GPIO27_ADC1 39 GPIO2 4 GPIO28_ADC2 40 GPIO29_ADC3 41 IOVDD 42 ADC_AVDD 43 VREG_IN 44 VREG_VOUT 45 USB_DM 46 USB_DP 47 USB_VDD 48 IOVDD 49 GPIO3 5 DVDD 50 QSPI_SD3 51 QSPI_SCLK 52 QSPI_SD0 53 QSPI_SD2 54 QSPI_SD1 55 QSPI_SS 56 GND 57 GPIO4 6 GPIO5 7 GPIO6 8 GPIO7 9 GND

4 SDA 5 SCL 6 WP 7 VCC

1 DM1 10 DP1 11 VD18_O 12 VD33 13 REXT 14 DMU 15 DPU 16 ~{XRSTJ} 17 VBUSM 18 BUSJ 19 XOUT 2 VDD5 20 VD33_O 21 DRV 22

Id: 2/7 Title: Karabas-Mini File: rp2040.kicad_sch Sheet: /RP2040/




Id: 5/7 Title: Karabas-Mini File: vga.kicad_sch Sheet: /VGA/ R22


1 DQ5 10 DQ6 11 DQ7 13 DQML 15 ~{WE} 16 ~{CAS} 17 ~{RAS} 18 ~{CS} 19 DQ0 2 BA0 20 BA1 21 A10 22 A0 23 A1 24 A2 25 A3 26 VSS 28 A4 29 VDDQ

3 A5 30 A6 31 A7 32 A8 33 A9 34 A11 35 A12 36 CKE 37 CLK 38 DQMH 39 DQ1 4 DQ8 42 DQ9 44 DQ10 45 DQ11 47 DQ12 48 DQ2 5 DQ13 50 DQ14 51 DQ15 53 VSSQ

~{CS}2 DI 3 VDD 4 SCLK 5 GND 6 DO 7 CD1 9 J4
uSD card

~{CS}2 DI 3 VDD 4 SCLK 5 GND 6 DO 7 CD1 9 J5

Id: 7/7 Title: Karabas-Mini File: storage.kicad_sch Sheet: /Storage/ CD2 10 SH 11 SH 12 SH 13 SH 14 SH 15


1 VO 2 VI 3 GND GND GND R54 470 C81 100n U17 ESP-12E

1 VO 2 VI 3 VCC C55 100n GND C59 100n 300 R41 GND GND GND GND C58 100n GND GND

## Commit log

2024-04-17 Added case 3d model
    [karabas-mini-case-bottom.stl, karabas-mini-case-top.stl]
2024-04-17 Added CF card shield gerbers
2024-05-27 Updated firmware + joy drivers
2024-05-27 Added joy drivers into the howto
2024-06-02 Added shield for revF + case for revF (with or without shield)
    [karabas-mini-case-v2-bottom.stl, karabas-mini-case-v2-top.stl, karabas-mini-case-v2cf-bottom.stl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]
2024-06-23 Added alternative flag type right angled usb type-c connector
2024-07-11 Added usb gamepad driver
2024-09-24 Added autofire on buttons X,Y
2025-10-04 Added revG dev pcb set
2025-12-24 ESP32-S3 working firmware and utilities
2025-12-25 Updated tsconf core with recent upstream changes to zports and spi
2026-01-09 Experimental ZIFI support over ESP32-S3 SPI
2026-03-24 ZX Spectrum Next core build 26032411 with fixed NMI buttons
2026-04-15 Updated ESP32-S3 firmware + Gopher client
2026-04-24 Updated case models for revF and revG - fixed upper standoffs
    [karabas-mini-case-v2cf-bottom.stl, karabas-mini-case-v2cf-top.stl]
2026-04-26 Latest esp32-s3 firmware
2026-05-10 TSConf core with hw buttons support
2026-06-11 updated shield v4 gerbers
2026-06-12 Updated shield v4 gerbers + docs
2026-07-03 Added case v4 with CF + dot matrix display
    [cylinder_6x6x3.stl, karabas-mini-case-v4cfdisp-bottom.stl, karabas-mini-case-v4cfdisp-top.stl]
2026-07-26 Colourful case for MMU-enabled 3d printers
    [karabas-mini-case-v4cfdisp-top-MMU-LOGO.3mf]
2026-10-15 Firmware with image mount / burst transfers support
2026-10-15 Added eject option for mounted images
2026-10-16 Fixed CF block writes, added audio filter
2026-10-20 Boot menu build 26102001: kg_* modules, ESP uart and FT812 HDMI fixes
2026-10-23 Spec256 build 26102321: SDR_CLK phase fix (background artefacts on some boards)
2026-10-25 Firmware build 26102517: USB printer host (Epson LX-300) and XInput gamepads (8BitDo M30)
2026-10-25 Firmware build 26102519: USB joysticks: shared stable ports, drivers on the heap, fixes
2026-10-25 Firmware build 26102520: Driver ini v2: hat, axis ranges, inverted bits, several sources, report id
2026-10-25 Firmware build 26102523_113: Graphic setup: Esc asks before dropping changes, S button, G key, sound speed
2026-10-26 Firmware build 26102617: On-board buttons by the actions of the core (core.json buttons); MSC screen, no buttons at boot
2026-10-26 Firmware build 26102619: LED matrix: more effects, drive activity, karabas.ini [matrix]
2026-10-26 Boot menu build 26102619: LED matrix shows the board name once, then the clock
2026-10-26 Firmware build 26102620: USB host: 3 hubs, 8 devices, 16 HID interfaces, 1024-byte enumeration buffer
2026-10-26 Firmware build 26102623: MSC eject: reboot when the host lets the device go, or 5 s after; SD2 transfers retried
2026-10-26 Firmware build 26102700: Serial bridge: flush the USB CDC every tick (ESP / core UART replies came late)
2026-10-27 Firmware build 26102701: LED matrix: the look of the clock and the audio meters in karabas.ini, Matrix effects page
2026-10-27 Firmware build 26102703: USB diagnostics: root port events, SOF timing, pin state, TinyUSB errors in the log
2026-10-27 Firmware build 26102713: USB host: upstream Pico-PIO-USB 0.7.3, the whole usb host on pio1
2026-10-28 Firmware build 26102802: Firmware in C11 on the pico-sdk: CMake, FreeRTOS, TinyUSB directly, the UI refactoring
2026-10-28 Firmware build 26102811: XInput: wake third-party Xbox 360 wired pads (no input since the pico-sdk move)
2026-10-28 Firmware build 26102813_300: Audit leftovers: less static RAM, printer on usb_host_lock, CMD_MATRIX_BITPLAN
2026-10-28 Firmware build 26102815_311: FT background: native CMD_GRADIENT; flat buttons in 800x600
2026-10-28 Firmware build 26102816: Text OSD: full width Setup screens, centered buttons, core menu style choices
2026-10-30 Firmware build 26103022: Karabas Go: PCA9536 found by a register read, buttons as outputs high, read errors logged
2026-10-30 Firmware build 26103023: OSD file lists: filter by the item's extensions, show them, dirs with '/' in cyan
2026-10-30 Spec256 build 26103101: video 720x576 at 50 Hz, games at Spectrum speed
2026-10-31 PC XT build 26103107: OSD, HDD and floppy images, Sergey XT BIOS, DMA / 8288 / CPU microcode fixes
2026-10-31 Firmware build 26103114: USB MIDI keyboards: host class driver, CMD_MIDI 0x16 to cores with caps bit 4
2026-10-31 PC XT build 26103112: HDMI frame buffer in SDRAM (Mini / Mini G), Sergey BIOS 1.0.2, XTIDE r638
2026-10-31 PC/XT core 26103113: two joysticks, COM2 over USB, LPT1 on the USB printer
2026-10-31 Firmware build 26103118: USB-UART adapters on the USB host take the core UART
2026-10-31 PC/XT core 26103116: Sergey XT BIOS 1.0.2 with AdLib detection and the OPL power-on melody
2026-11-01 Firmware build 26110118: CMD_FDD_CHNG 49: DSKCHG of the Go floppy through a hotfix wire on GPIO28
2026-11-02 NanoMig 26110106 (Mini, Mini G): the floppy fifo fix
    The fix of the floppy fifo (a stale word when the only word was read in the
    cycle the next one was written) is shared logic; with ADF images the case is
    rare, so there was no known symptom. Not tested on hardware yet. Core:
    karabas-go-core-nanomig PR #14.
2026-11-02 BaseConf 26110107: ERS 0.61 without DOS_FE again, TRD images mount in the ERS
2026-11-02 BaseConf 26110201: TR-DOS emulation of base_trdemu, ERS 0.61.01 FE (TRD mount through dos_fe)
2026-11-04 Firmware build 26110414: Read kgo2 core files (.kg): one file for several boards
2026-11-04 Cores as kgo2 files (.kg): one file for Go, Mini and Mini G
    Every core of cores/ is now one .kg file with the bitstreams of all the boards
    (karabas-go-tools docs/kgo2.md), packed from the core repos (their kgo2 PRs)
    without a new build; pong.kg is converted from the old pong.kg1 (no sources).
    karabas-go-tools kg_compare.py: each board gets what the old .kg1 / .kg2 /
    .kg3 gave, except next186 on Mini / Mini G, which now has the BIOS of the Go
    build 26110101 (the one in the core repo). The settings of a .kg core are kept
    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
2026-11-04 The cores are in karabas-go now: no cores/ here, README says where they are
    One .kg per core serves all the boards, so it lives in one release repo,
    karabas-go (cores/). The .kg2 / .kg3 files and the .kg copies of the branch
    go; README.md (en / ru), docs/howto.md and CLAUDE.md point to karabas-go and
    to the firmware 26110415 or later.

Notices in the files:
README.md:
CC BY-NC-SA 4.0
